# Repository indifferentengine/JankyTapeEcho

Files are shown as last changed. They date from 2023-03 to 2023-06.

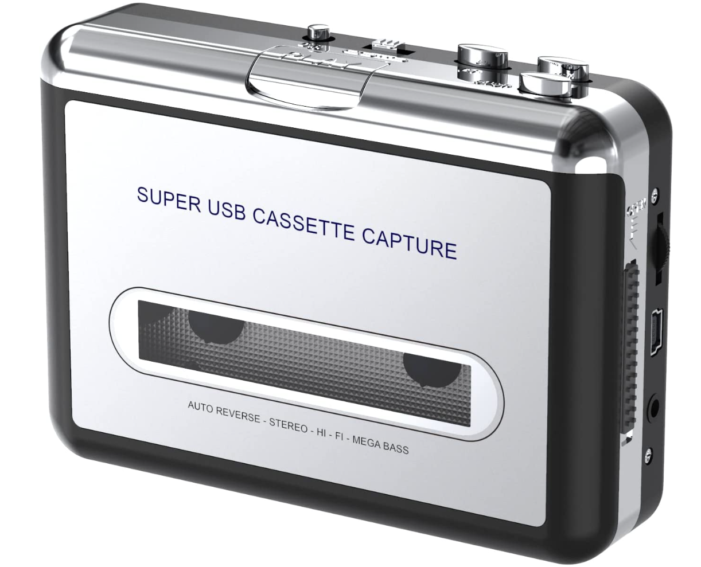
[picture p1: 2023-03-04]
Required Tape Machine.png

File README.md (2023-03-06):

# Indifferent Engine Janky Tape Echo

An open-source, DIY tape echo effect pedal built from a cheap cassette player and 3D printed parts.

# Demo Video

This is kinda what this thing sounds like.

Demonstration Video (https://www.youtube.com/watch?v=j26JLl0Hhg4)

# License

This device is licensed under GNU GPL v3. This means you are free to take this device and make any changes you like and then share those changes freely, **so long as you make the source for your changes publicly available**. This benefits everyone - because if you make some improvement, we can all benefit from it.

However, you **cannot distribute compiled versions.** In this context (a hardware device with software components), this effectively means you

a)  **cannot sell any physically manufactured device of any kind - either as parts or assembled.** 

b) **cannot charge money for access to any source, CAD files or software components that you choose to distribute** that are based upon this project.
  
If you **break these simple rules** we will force you to be front row at one of our floor shows, where we can **full-throat scream right in your sad little face.**

Everything is copyright (c) 2023 Indifferent Engine Ltd. Everything. OK?
Indifferent Engine and the Indifferent Engine glitch logo are trademarks of Indifferent Engine Ltd.

# What You Get

* STL files for 3D printed parts
* Gerber files for PCBs
* Source code for Arduino
* Bill of Materials
* CAD files in Step format.
* Eagle schematic files.
* Eagle board blanks (boards of correct dimensions with Jacks in correct locations).
* Build instructions (via our website)

# What You Don't Get

* Full Eagle board files
* Any support from us what-so-ever.

# Build guide

To show you how to put one of these together, there is a [build guide](https://www.indifferentengine.com/tapeechobuildguide) on our website.

# PCB

We sell PCBs for this project on our [merch store](https://www.indifferentengine.com/shop).

# How can we support you?

Indifferent Engine is a band, so go check out our music here:
[spotify](https://open.spotify.com/artist/0dltTUV2N49r1UjUTsqe3h?si=cdwmojcwTOmE14S_XvX_6A)

If you're having a crack at building an echo, maybe buy some parts from us on our [merch store](https://www.indifferentengine.com/shop).. All money goes back into the band for funding musical endeavours and more weird, open source pedal designs.

You can also follow us in the usual places:
[instagram](https://www.instagram.com/indifferentengine)
[facebook](https://www.facebook.com/indifferentengine)
[tiktok](https://www.tiktok.com/@indifferentengine)
[youtube](https://www.youtube.com/@indifferentengine)

And **buy a T-Shirt while you're at it**, you bunch of scallywags.

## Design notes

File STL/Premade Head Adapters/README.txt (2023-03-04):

These are pre-made head adapters to fit the Janky Tape Echo.

A word of caution:

Cassette heads are very sensitive to being aligned to the tape path correctly. 3D prints have wide tolerances
that can be hard to get right at these small scales.

Because of this, you will need to be very careful to have your 3D printer tuned up for best possible dimensional
accuracy and to use a very high quality profile (lowest possible layer height and low speed printing) to ensure the head
adapter has the tightest tolerances.

3D prints tend to shrink, some filaments more than others, and so it's impossible for us to say these head adapters will work for
everybody - they are provided as an easy "try this first" route for people. It's quite possible you'll need to design your own
head adapter to work with your setup. Check out our build guide on our website for step-by-step instructions on how to do this with free CAD software.

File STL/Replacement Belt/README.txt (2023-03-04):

This is a replacement belt for the Janky tape transport.

Print in flex filament (TPU or similar).

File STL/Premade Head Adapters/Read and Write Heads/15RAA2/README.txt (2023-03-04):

This is for 15RAA2 cassette head.

Print at highest detail possible to ensure dimensional accuracy. We print these on a Prusa Mini using the built-in Generic PLA filament profile at
0.05mm ULTRADETAIL, 15% infill in polyterra charcoal black PLA.

Space is provided around the right mounting hole (looking from the front of the head) for a spring (5mm length, 0.2mm wire, 2.5mm OD to allow pass through of M2 screw).
This allows for aziumth adjustment of the head, but is optional. If you are using the spring, place a M2 washer between the top of the spring and the underside of the head.

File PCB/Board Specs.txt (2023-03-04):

Board Specs

Mainboard:
100mm x 84mm
2 Layers
Designed to 6/6mil minimum track spacing

Control board:
126mm x 59mm
2 Layers
Designed to 6/6mil minimum track spacing

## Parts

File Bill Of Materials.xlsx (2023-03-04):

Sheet: Parts In Order Of Usage
This page contains the electronic parts in order of usage in the build instructional videos. For a complete list of parts including hardware and tools, please check the ALL PARTS page in this file. PCBs are available to buy from the bands website: https://www.indifferentengine.com Gerber files are also included in this package if you'd rather save some money and make your own boards. You cheapskate. 3D printed parts and/or kits may be available from our merch store. Take a look and see what we have. For instructions, troubleshooting tips etc. please visit the Tape Echo section of our site: https://www.indifferentengine.com/tapeecho
The Jacks
Part | Value | Description | Notes
INPUT | Audio Jack | PCB mount 3/4" audio jack
OUTPUT | Audio Jack | PCB mount 3/4" audio jack
DC1 | DC Jack | Boss-style 2.1mm DC Jack
The Ground Link
GND LINK | 0R | Zero Ohm Link | This is just a 0 Ohm link between the digital ground and analog ground. This is done to make sure there is only 1 path between digital ground and analog ground for the purposes of improving noise performance. I use a either some solid-core wire, or a discarded component leg from a resistor or capacitor to make the link.
The JST XH Headers
ERASE | 2-way JST XH Header | 2-way JST XH Male Terminal. 2.54mm lead pitch.
PLAYBACK | 2-way JST XH Header | 2-way JST XH Male Terminal. 2.54mm lead pitch.
RECORD | 2-way JST XH Header | 2-way JST XH Male Terminal. 2.54mm lead pitch.
REMOTE | 2-way JST XH Header | 2-way JST XH Male Terminal. 2.54mm lead pitch.
TAPEPWR | 2-way JST XH Header | 2-way JST XH Male Terminal. 2.54mm lead pitch.
MOTOR | 3-way JST XH Header | 3-way JST XH Male Terminal. 2.54mm lead pitch. | We use a 3 way header because we use a spare pin to ground the motor casing. This helps reduce noise.
The IDC Box Header
CNTRLBRD | IDC Box Header | 26-way IDC box header for connection to control board | Must be a 26-way, 2 row IDC box header.
12V Main Supply
D1 | 1n4001 | Polarity protection diode
C1 | 1000uF | Electrolytic capacitor, 16V, 8mm diameter
9V Bias Oscillator Supply
R26 | 10K | 1/4W Metal Film Resistor, 7.5mm diameter
R27 | 100R | 1/4W Metal Film Resistor, 7.5mm diameter
C9 | 100nF | Ceramic capacitor, 16V, 5mm diameter
C10 | 100nF | Ceramic capacitor, 16V, 5mm diameter
C11 | 10uF | Electrolytic capacitor, 16V, 5mm diameter
C12 | 1000uF | Electrolytic capacitor, 16V, 8mm diameter
9VREG | 7809 | Positive VOLTAGE REGULATOR, 9V Output | Ensure correct pinout: INPUT, GND, OUTPUT
Q5 | RFP12N10L | N-channel, logic level MOSFET | For oscillator disable control
6V Motor Supply
6VREG | 7806 | Positive VOLTAGE REGULATOR, 6V Output | Ensure correct pinout: INPUT, GND, OUTPUT
C15 | 100nF | Ceramic capacitor, 16V, 5mm diameter
C16 | 100nF | Ceramic capacitor, 16V, 5mm diameter
C17 | 10uF | Electrolytic capacitor, 16V, 5mm diameter
3V3 Tape Player Supply
3V3REG | LD1086V33 | Positive VOLTAGE REGULATOR, 3.3V Output | Ensure correct pinout: GND, OUTPUT, INPUT This is different to the other 2 regulators.
C25 | 100nF | Ceramic capacitor, 16V, 5mm diameter
C26 | 100nF | Ceramic capacitor, 16V, 5mm diameter
C27 | 10uF | Electrolytic capacitor, 16V, 5mm diameter
Buffered Virtual Ground
R10 | 10K | 1/4W Metal Film Resistor, 7.5mm diameter
R11 | 10K | 1/4W Metal Film Resistor, 7.5mm diameter
R12 | 100R | 1/4W Metal Film Resistor, 7.5mm diameter
OPAMP3 | TL072 | TL072 Dual Op Amp (or equivalent)
C20 | 100n | Ceramic capacitor, 16V, 5mm diameter
C21 | 100uF | Electrolytic capacitor, 16V, 5mm diameter
C22 | 100n | Ceramic capacitor, 16V, 5mm diameter
C23 | 100uF | Electrolytic capacitor, 16V, 5mm diameter
C24 | 100n | Ceramic capacitor, 16V, 5mm diameter
Arduino Nano
ARDUINO_NANO | Arduino Nano | Arduino Nano V3.0 Module
True Bypass Switching
R6 | 10K | 1/4W Metal Film Resistor, 7.5mm diameter
R7 | 10K | 1/4W Metal Film Resistor, 7.5mm diameter
Q4 | 2N2222 | NPN Transistor | For relay bypass switching
RELAY | 5-1462039-9 | Non-Latching, DPDT Signal Relay, 5V | https://uk.farnell.com/te-connectivity/im03pns/relay-signal-dpdt-250vac-220vdc/dp/1770596
The Motor Controller
R8 | 10K | 1/4W Metal Film Resistor, 7.5mm diameter
R9 | 100R | 1/4W Metal Film Resistor, 7.5mm diameter
D2 | 1n4001 | Back propagation protection diode
Q1 | RFP12N10L | N-channel, logic level MOSFET | High current MOSFET for motor control. Must be logic level to interface with Arduino.
C18 | 100nF | Ceramic capacitor, 16V, 5mm diameter
C19 | 1000uF | Electrolytic capacitor, 16V, 8mm diameter
Mainboard Input Stage
R4 | 4K7 | 1/4W Metal Film Resistor, 7.5mm diameter
R5 | 0R | 1/4W Metal Film Resistor, 7.5mm diameter | This is included as a way to adjust coil resistance for tuning purposes. If in doubt, use 0R (use solid core wire or a discarded component leg)
R13 | 1K | 1/4W Metal Film Resistor, 7.5mm diameter
R14 | 1M | 1/4W Metal Film Resistor, 7.5mm diameter
R15 | 1K | 1/4W Metal Film Resistor, 7.5mm diameter
R16 | 1K | 1/4W Metal Film Resistor, 7.5mm diameter
R17 | 400R | 1/4W Metal Film Resistor, 7.5mm diameter
R18 | 100K | 1/4W Metal Film Resistor, 7.5mm diameter
OPAMP2 | TL072 | TL072 Dual Op Amp (or equivalent)
C13 | *pF | Film capacitor, 100V, 5mm diameter | For tuning bias trap notch filter. A good starting place is C13 as 1nF and C14 as NONE. Must be 100V rated
C14 | *pF | Film capacitor, 100V, 5mm diameter | Optional. Extra capacitor space for combining values with C13 (to make non-standard cap values for trap tuning) Must be 100V rated
C28 | 100n | Film capacitor, 16V, 5mm diameter
C29 | 100n | Ceramic capacitor, 16V, 5mm diameter
C30 | 100pF | Film capacitor, 16V, 5mm diameter
C31 | 10uF | Electrolytic capacitor, 100V, 5mm diameter | Must be 100V rated
INDUCTOR | 10mH | Radial Inductor | For bias trap. If different value used, capacitors C13 and C14 in the tank circuit must be calculated accordingly.
Mainboard Output Stage
R19 | 1M | 1/4W Metal Film Resistor, 7.5mm diameter
R20 | 22K | 1/4W Metal Film Resistor, 7.5mm diameter
R21 | 22K | 1/4W Metal Film Resistor, 7.5mm diameter
R22 | 10K | 1/4W Metal Film Resistor, 7.5mm diameter
R23 | 1K | 1/4W Metal Film Resistor, 7.5mm diameter
R24 | 1M | 1/4W Metal Film Resistor, 7.5mm diameter
R25 | 560R | 1/4W Metal Film Resistor, 7.5mm diameter
OPAMP1 | TL072 | TL072 Dual Op Amp (or equivalent)
C32 | 220n | Film capacitor, 16V, 5mm diameter
C33 | 1nF | Film capacitor, 16V, 5mm diameter
C34 | 2.2nF | Film capacitor, 16V, 5mm diameter
C35 | 100pF | Film capacitor, 16V, 5mm diameter
C36 | 100n | Ceramic capacitor, 16V, 5mm diameter
C37 | 10uF | Electrolytic capacitor, 16V, 5mm diameter
Control Board IDC Header
MAINBOARD | IDC Box Header | 26-way IDC box header for connection to control board | Must be a 26-way, 2 row IDC box header.
Control Board JST XH Headers
HEAD_LONG | 3-way JST XH Header | 3-way JST XH Male Terminal. 2.54mm lead pitch.
HEAD_OUT | 3-way JST XH Header | 3-way JST XH Male Terminal. 2.54mm lead pitch.
HEAD_SHORT | 3-way JST XH Header | 3-way JST XH Male Terminal. 2.54mm lead pitch.
Control Board Bias Trap
INDUCTOR | 10mH | Radial Inductor | For bias trap. If different value used, capacitors C6 and C7 in the tank circuit must be calculated accordingly.
C6 | *pF | Film capacitor, 16V, 5mm diameter | For tuning bias trap notch filter. A good starting place is C13 as 1nF and C14 as NONE.
C7 | *pF | Film capacitor, 16V, 5mm diameter | Optional. Extra capacitor space for combining values with C13 (to make non-standard cap values for trap tuning)
Control Board Input Filtering and Feedback Mix
R4 | 1K6 | 1/4W Metal Film Resistor, 7.5mm diameter
R7 | 2K2 | 1/4W Metal Film Resistor, 7.5mm diameter
R8 | 2K2 | 1/4W Metal Film Resistor, 7.5mm diameter
R9 | 2K2 | 1/4W Metal Film Resistor, 7.5mm diameter
R10 | 1K | 1/4W Metal Film Resistor, 7.5mm diameter
R11 | 1K | 1/4W Metal Film Resistor, 7.5mm diameter
R12 | 100K | 1/4W Metal Film Resistor, 7.5mm diameter
R13 | 2K2 | 1/4W Metal Film Resistor, 7.5mm diameter
R14 | 10K | 1/4W Metal Film Resistor, 7.5mm diameter
R15 | 10K | 1/4W Metal Film Resistor, 7.5mm diameter
R16 | 100K | 1/4W Metal Film Resistor, 7.5mm diameter
R17 | 1M | 1/4W Metal Film Resistor, 7.5mm diameter
OPAMP1 | TL072 | TL072 Op Amp (or equivalent)
OPAMP2 | TL072 | TL072 Op Amp (or equivalent)
BASS | 10K | Trimpot
TREBLE | 10K | Trimpot
C2 | 100nF | Ceramic capacitor, 16V, 5mm diameter
C3 | 18nF | Film capacitor, 16V, 5mm diameter
C4 | 220nF | Film capacitor, 16V, 5mm diameter
C5 | 100nF | Ceramic capacitor, 16V, 5mm diameter
Control Board Output Stage
R5 | 1K | 1/4W Metal Film Resistor, 7.5mm diameter
R6 | 1M | 1/4W Metal Film Resistor, 7.5mm diameter
POSTGAIN | 10K | Trimpot
C1 | 10nF | Film capacitor, 16V, 5mm diameter
Front Panel Potentiometers
TIME | 10K Linear | 9mm Alpha Potentiometer, Metal D-Shaft
BRIGHTNES | 50K Linear | 9mm Alpha Potentiometer, Metal D-Shaft
FEEDBACK | 10K Linear | 9mm Alpha Potentiometer, Metal D-Shaft
GAIN | 10K Linear | 9mm Alpha Potentiometer, Metal D-Shaft
MIX | 100K Linear | 9mm Alpha Potentiometer, Metal D-Shaft
JANK | 10K Linear | 9mm Alpha Potentiometer, Metal D-Shaft
Head Select Switch
HEAD SWITCH | 3PDT Toggle | Panel mounted 3PDT On-On toggle switch
Bias Oscillator
R1 | 10K | 1/4W Metal Film Resistor, 7.5mm diameter
R2 | 10K | 1/4W Metal Film Resistor, 7.5mm diameter
R3 | 1K | 1/4W Metal Film Resistor, 7.5mm diameter
Q2 | BC327 | PNP Transistor
Q3 | BC337 | NPN Transistror
C2 | 22uF | Electrolytic capacitor, 100V, 5mm diameter | Must be 100V rated.
C3 | 22uF | Electrolytic capacitor, 100V, 5mm diameter | Must be 100V rated
C4 | 1uF | Ceramic multilayer capacitor, 100V | Must be 100V rated
C5 | 10nF | Film capacitor, 100V, 5mm diameter | Must be 100V rated
C6 | 100nF | Ceramic multilayer capacitor, 100V | Must be 100V rated
C7 | 100nF | Ceramic multilayer capacitor, 100V | Must be 100V rated
C8 | 100pF | Film capacitor, 100V, 5mm diameter | Must be 100V rated
BIASLEVEL | 100K | Trimpot | Bias attenuator

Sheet: ALL PARTS
MAIN BOARD
Part | Value | Description | Notes | Useful Links
3V3REG | LD1086V33 | Positive VOLTAGE REGULATOR, 3.3V Output | Ensuire correct pinout: GND, OUTPUT, INPUT This is different to the other 2 regulators.
6VREG | 7806 | Positive VOLTAGE REGULATOR, 6V Output | Ensuire correct pinout: INPUT, GND, OUTPUT
9VREG | 7809 | Positive VOLTAGE REGULATOR, 9V Output | Ensuire correct pinout: INPUT, GND, OUTPUT
ARDUINO_NANO | Arduino Nano | Arduino Nano V3.0 Module
OPAMP1 | TL072 | TL072 Dual Op Amp (or equivalent)
OPAMP2 | TL072 | TL072 Dual Op Amp (or equivalent)
OPAMP3 | TL072 | TL072 Dual Op Amp (or equivalent)
D1 | 1n4001 | Polarity protection diode
D2 | 1n4001 | Back propagation protection diode
Q1 | RFP12N10L | N-channel, logic level MOSFET | High current MOSFET for motor control. Must be logic level to interface with Arduino.
Q2 | BC327 | PNP Transistror
Q3 | BC337 | NPN Transistor
Q4 | 2N2222 | NPN Transistor | For relay bypass switching
Q5 | RFP12N10L | N-channel, logic level MOSFET | For oscillator disable control
INDUCTOR | 10mH | Radial Inductor | For bias trap. If different value used, capacitors C13 and C14 in the tank circuit must be calculated accordingly.
C1 | 1000uF | Electrolytic capacitor, 16V, 8mm diameter
C2 | 22uF | Electrolytic capacitor, 100V, 5mm diameter | Must be 100V rated
C3 | 22uF | Electrolytic capacitor, 100V, 5mm diameter | Must be 100V rated
C4 | 1uF | Ceramic multilayer capacitor, 100V | Must be 100V rated
C5 | 10nF | Film capacitor, 100V, 5mm diameter | Must be 100V rated
C6 | 100nF | Ceramic multilayer capacitor, 100V | Must be 100V rated
C7 | 100nF | Ceramic multilayer capacitor, 100V | Must be 100V rated
C8 | 100pF | Film capacitor, 100V, 5mm diameter | Must be 100V rated
C9 | 100nF | Ceramic capacitor, 16V, 5mm diameter
C10 | 100nF | Ceramic capacitor, 16V, 5mm diameter
C11 | 10uF | Electrolytic capacitor, 16V, 5mm diameter
C12 | 1000uF | Electrolytic capacitor, 16V, 8mm diameter
C13 | *pF | Film capacitor, 100V, 5mm diameter | For tuning bias trap notch filter. A good starting place is C13 as 1nF and C14 as NONE. Must be 100V rated
C14 | *pF | Film capacitor, 100V, 5mm diameter | Optional. Extra capacitor space for combining values with C13 (to make non-standard cap values for trap tuning) Must be 100V rated
C15 | 100nF | Ceramic capacitor, 16V, 5mm diameter
C16 | 100nF | Ceramic capacitor, 16V, 5mm diameter
C17 | 10uF | Electrolytic capacitor, 16V, 5mm diameter
C18 | 100nF | Ceramic capacitor, 16V, 5mm diameter
C19 | 1000uF | Electrolytic capacitor, 16V, 8mm diameter
C20 | 100n | Ceramic capacitor, 16V, 5mm diameter
C21 | 100uF | Electrolytic capacitor, 16V, 5mm diameter
C22 | 100n | Ceramic capacitor, 16V, 5mm diameter
C23 | 100uF | Electrolytic capacitor, 16V, 5mm diameter
C24 | 100n | Ceramic capacitor, 16V, 5mm diameter
C25 | 100nF | Ceramic capacitor, 16V, 5mm diameter
C26 | 100nF | Ceramic capacitor, 16V, 5mm diameter
C27 | 10uF | Electrolytic capacitor, 16V, 5mm diameter
C28 | 100n | Film capacitor, 16V, 5mm diameter
C29 | 100n | Ceramic capacitor, 16V, 5mm diameter
C30 | 100pF | Film capacitor, 16V, 5mm diameter
C31 | 10uF | Electrolytic capacitor, 100V, 5mm diameter | Must be 100V rated
C32 | 220n | Film capacitor, 16V, 5mm diameter
C33 | 1nF | Film capacitor, 16V, 5mm diameter
C34 | 2.2nF | Film capacitor, 16V, 5mm diameter
C35 | 100pF | Film capacitor, 16V, 5mm diameter
C36 | 100n | Ceramic capacitor, 16V, 5mm diameter
C37 | 10uF | Electrolytic capacitor, 16V, 5mm diameter
BIASLEVEL | 100K | Trimpot | Bias attenuator trimpot.
R1 | 10K | 1/4W Metal Film Resistor, 7.5mm diameter
R2 | 10K | 1/4W Metal Film Resistor, 7.5mm diameter
R3 | 1K | 1/4W Metal Film Resistor, 7.5mm diameter
R4 | 4K7 | 1/4W Metal Film Resistor, 7.5mm diameter
R5 | 0R | 1/4W Metal Film Resistor, 7.5mm diameter | This is included as a way to adjust coil resistance for tuning purposes. If in doubt, use 0R (use solid core wire or a discarded component leg)
R6 | 10K | 1/4W Metal Film Resistor, 7.5mm diameter
R7 | 10K | 1/4W Metal Film Resistor, 7.5mm diameter
R8 | 10K | 1/4W Metal Film Resistor, 7.5mm diameter
R9 | 100R | 1/4W Metal Film Resistor, 7.5mm diameter
R10 | 10K | 1/4W Metal Film Resistor, 7.5mm diameter
R11 | 10K | 1/4W Metal Film Resistor, 7.5mm diameter
R12 | 100R | 1/4W Metal Film Resistor, 7.5mm diameter
R13 | 1K | 1/4W Metal Film Resistor, 7.5mm diameter
R14 | 1M | 1/4W Metal Film Resistor, 7.5mm diameter
R15 | 1K | 1/4W Metal Film Resistor, 7.5mm diameter
R16 | 1K | 1/4W Metal Film Resistor, 7.5mm diameter
R17 | 400R | 1/4W Metal Film Resistor, 7.5mm diameter
R18 | 100K | 1/4W Metal Film Resistor, 7.5mm diameter
R19 | 1M | 1/4W Metal Film Resistor, 7.5mm diameter
R20 | 22K | 1/4W Metal Film Resistor, 7.5mm diameter
R21 | 22K | 1/4W Metal Film Resistor, 7.5mm diameter
R22 | 10K | 1/4W Metal Film Resistor, 7.5mm diameter
R23 | 1K | 1/4W Metal Film Resistor, 7.5mm diameter
R24 | 1M | 1/4W Metal Film Resistor, 7.5mm diameter
R25 | 560R | 1/4W Metal Film Resistor, 7.5mm diameter
R26 | 10K | 1/4W Metal Film Resistor, 7.5mm diameter
R27 | 100R | 1/4W Metal Film Resistor, 7.5mm diameter
RELAY | 5-1462039-9 | Non-Latching, DPDT Signal Relay, 5V | https://uk.farnell.com/te-connectivity/im03pns/relay-signal-dpdt-250vac-220vdc/dp/1770596
CNTRLBRD | IDC Box Header | 26-way IDC box header for connection to control board | I found these on E-bay. Must be a 26-way IDC box header.
DC1 | DC Jack | Boss-style 2.1mm DC Jack
INPUT | Audio Jack | PCB mount 3/4" audio jack
OUTPUT | Audio Jack | PCB mount 3/4" audio jack
ERASE | 2-way JST XH Header | 2-way JST XH Male Terminal. 2.54mm lead pitch.
PLAYBACK | 2-way JST XH Header | 2-way JST XH Male Terminal. 2.54mm lead pitch.
RECORD | 2-way JST XH Header | 2-way JST XH Male Terminal. 2.54mm lead pitch.
REMOTE | 2-way JST XH Header | 2-way JST XH Male Terminal. 2.54mm lead pitch.
TAPEPWR | 2-way JST XH Header | 2-way JST XH Male Terminal. 2.54mm lead pitch.
HEAD_LONG | 3-way JST XH Header | 3-way JST XH Male Terminal. 2.54mm lead pitch.
HEAD_OUT | 3-way JST XH Header | 3-way JST XH Male Terminal. 2.54mm lead pitch.
HEAD_SHORT | 3-way JST XH Header | 3-way JST XH Male Terminal. 2.54mm lead pitch.
MOTOR | 3-way JST XH Header | 3-way JST XH Male Terminal. 2.54mm lead pitch. | We use a 3 way header because we use a spare pin to ground the motor casing. This helps reduce noise.
GND LINK | 0R | Zero Ohm Link | This is just a 0 Ohm link between the digital ground and analog ground. This is done to make sure there is only 1 path between digital ground and analog ground for the purposes of improving noise performance. I use a either some solid-core wire, or a discarded component leg from a resistor or capacitor to make the link.
CONTROL BOARD
Part | Value | Description | Notes
OPAMP1 | TL072 | TL072 Op Amp (or equivalent)
OPAMP2 | TL072 | TL072 Op Amp (or equivalent)
Q1 | RFP12N10L | N-channel, logic level MOSFET | Optional, for LED strip lighting. Must be logic level to interface with Arduino.
INDUCTOR | 10mH | Radial Inductor | For bias trap. If different value used, capacitors C13 and C14 in the tank circuit must be calculated accordingly.
C1 | 10nF | Film capacitor, 16V, 5mm diameter
C2 | 100nF | Ceramic capacitor, 16V, 5mm diameter
C3 | 18nF | Film capacitor, 16V, 5mm diameter
C4 | 220nF | Film capacitor, 16V, 5mm diameter
C5 | 100nF | Ceramic capacitor, 16V, 5mm diameter
C6 | *pF | Film capacitor, 100V, 5mm diameter | For tuning bias trap notch filter. A good starting place is C13 as 1nF and C14 as NONE. Must be 100V rated
C7 | *pF | Film capacitor, 100V, 5mm diameter | Optional. Extra capacitor space for combining values with C13 (to make non-standard cap values for trap tuning) Must be 100V rated
R4 | 1K6 | 1/4W Metal Film Resistor, 7.5mm diameter
R5 | 1K | 1/4W Metal Film Resistor, 7.5mm diameter | Sets minimum position of brightness control.
R6 | 1M | 1/4W Metal Film Resistor, 7.5mm diameter
R7 | 2K2 | 1/4W Metal Film Resistor, 7.5mm diameter
R8 | 2K2 | 1/4W Metal Film Resistor, 7.5mm diameter
R9 | 2K2 | 1/4W Metal Film Resistor, 7.5mm diameter
R10 | 1K | 1/4W Metal Film Resistor, 7.5mm diameter
R11 | 1K | 1/4W Metal Film Resistor, 7.5mm diameter
R12 | 100K | 1/4W Metal Film Resistor, 7.5mm diameter
R13 | 2K2 | 1/4W Metal Film Resistor, 7.5mm diameter
R14 | 10K | 1/4W Metal Film Resistor, 7.5mm diameter
R15 | 10K | 1/4W Metal Film Resistor, 7.5mm diameter
R16 | 100K | 1/4W Metal Film Resistor, 7.5mm diameter
R17 | 1M | 1/4W Metal Film Resistor, 7.5mm diameter
TIME | 10K Linear | 9mm Alpha Potentiometer, Metal D-Shaft |  | https://www.thonk.co.uk/shop/alpha-9mm-pots-dshaft/
BRIGHTNES | 50K Linear | 9mm Alpha Potentiometer, Metal D-Shaft |  | https://www.thonk.co.uk/shop/alpha-9mm-pots-dshaft/
FEEDBACK | 10K Linear | 9mm Alpha Potentiometer, Metal D-Shaft |  | https://www.thonk.co.uk/shop/alpha-9mm-pots-dshaft/
GAIN | 10K Linear | 9mm Alpha Potentiometer, Metal D-Shaft |  | https://www.thonk.co.uk/shop/alpha-9mm-pots-dshaft/
MIX | 100K Linear | 9mm Alpha Potentiometer, Metal D-Shaft |  | https://www.thonk.co.uk/shop/alpha-9mm-pots-dshaft/
JANK | 10K Linear | 9mm Alpha Potentiometer, Metal D-Shaft |  | https://www.thonk.co.uk/shop/alpha-9mm-pots-dshaft/
BASS | 10K | Trimpot
TREBLE | 10K | Trimpot
POSTGAIN | 10K | Trimpot
MAINBRD | IDC Box Header | 26-way IDC box header for connection to control board | I found these on E-bay. Must be a 26-way IDC box header.
LED+ | LED Strip | 12V LED Strip, Positive terminal | Optional, for LED strip lighting
LED- | LED Strip | 12V LED Strip, Negative terminal | Optional, for LED strip lighting
Hardware
2mm diameter steel rod | 5 x 12mm lengths |  | To fit 12mm length - leaves ~1 mm space for easy fit. Can be cut to length with some strong pliers. Also available online from suppliers who will cut it to length for you. | https://www.rapidmetals.co.uk/product/stainless-316-round-2mm/
3 x M2 8mm Hex bolts |  |  | For mounting the cassette transport to the transport mount
M2 washers (various number, see notes) |  |  | For mounting cassette player to transport mount. These take up the extra distance between the 3D printed part and the transport - how many is needed varies between 6 and 10.
12 x M2 Hex Bolts (various length, see notes) |  |  | For mounting heads and head adapters. Length of bolts required depends on the size of your heads and adapters.
1 x M3 4mm Hex bolt |  |  | 1 x 4mm for attaching terminal washer to enclosure body (optional, for shielding)
11 x M3 8mm Hex bolts |  |  | 4 x 8mm for guide toppers 3 x 8mm for connecting transport mount to head mount 4 x 8mm for attaching acrylic window
4 x M3 16mm Hex bolts |  |  | For attaching reel clamps
4 x M4 65mm Hex Bolts |  |  | For the enclosure - bolts together the bottom plate, main body and enclosure lid.
15 x M3 Heat-Set Inserts |  |  | Brass, threaded inserts to be installed into the 3D printed parts using a soldering iron (and optional heat-set insert bit). The inserts allow us to open and close the enclosure many times for servicing without worrying about stripping the 3D printed plastic with the bolts.
4 x M4 Heat-Set Inserts |  |  | Brass, threaded inserts to be installed into the 3D printed parts using a soldering iron (and optional heat-set insert bit). The inserts allow us to open and close the enclosure many times for servicing without worrying about stripping the 3D printed plastic with the bolts.
6 x M3 Grub screw |  |  | 6 x 8mm M3 grub screws for attaching 3D printed knobs | https://www.aliexpress.com/item/33029779249.html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
Acrylic window |  |  | Clear acrylic - you can order this cut to size and drilled from many suppliers. I use SimplyPlastics. Specs are: Thickness: 5mm Length: 130mm Width: 65mm Corner Radius: 5mm Polished: Yes, Holes: 4 holes, one for each corner Hole diameter: 3mm at 10mm in from the edge. Holes countersunk: No If you know how then you can almost certainly do this much cheaper
3D Printer filament |  |  | PLA or PETG filaments are both suitable. I estimate ~440g of filament based on my slicer settings. At £25 for a 1KG roll, that's around £11 of filament
TO-220 Clip-On Heatsink |  |  | Heatsink for the 5V regulator. Clip-on heatsinks are available for TO-220 packages. This regulator generates a great deal of heat, and so I strongly recommend heatsinking your 5V regulator to extend its life.
1 x M3 wire ring terminal |  |  | A ring terminal washer for connecting a grounding wire to the enclosure body (if shielding is used)
Stereo angled 3.5mm audio cable |  |  | For connecting tape machine headphone jack to mainboard. Must be kind with 3 conductors (left, right, ground). We will cut one of the jacks off and cut the wire down to 10cm length. This must be angled, lest it not fit into the machine. See the link for an example. | https://smile.amazon.co.uk/gp/product/B072TYZ89H/ref=ppx_yo_dt_b_asin_title_o05_s00?ie=UTF8&psc=1
Bearings | 10 x (2mmx5mmx2mm) |  | Optional but recommended.Ten 682ZZ 2x5x2 bearings for tape path. These are placed over the steel tape guides to form a simple roller. This improves the smoothness of the tape path to lower flutter at low tape speeds. If you want a particularly lo-fi sounding device then leave these out! | https://www.aliexpress.com/item/33007670757.html
Tools
3D Printer |  |  | Hobbyist FDM 3D Printer with a useable print volume of 160mm x 150mm x 50mm or bigger.
Soldering Iron |  |  | Ideally with adjustable temperature for use with heat-set inserts.
Oscilloscope |  |  | A cheap hobbyist scope will do. These can be had quite cheap from places like Amazon (around £30)
Desoldering pump |  |  | Optional but recommended - for removing connectors from cassette machine PCB
Strong pliers |  |  | For cutting steel rods
Allen keys for M2, M3 and M4 bolts |  |  | For general assembly
Small phillps head screwdriver |  |  | For disassembling cassette machine
Small flat head screwdriver |  |  | For disassembling cassette machine
Anti-static tweezers |  |  | For installing the tape loop into the machine. Only the criminally insane would try to make loops without these.
A PC or Mac with USB connection |  |  | For flashing software to the Arduino for motor and switch control
Wire strippers
Calipers |  |  | Optional but recommended - preferably digital ones - these can be had online for quite cheap.
Set of Spanners |  |  | For tightening down the nuts on the potentiometers and jacks. Sizes depend on the parts used, but usually between 10mm and 14mm
Heat-set insert tool |  |  | A bit for your soldering iron that makes it easier to install heat-set inserts. Optional but recommended
Hot glue gun with glue |  |  | Optional but recommended. For securing wiring headers and ribbon cable in final assembly. Makes the machine a little more robust for use on the road by preventing wires from coming loose from the headers, whilst still allowing the machine to be easily serviced.
Lighter or heat gun |  |  | For using heat shrink tubing
Other
12V Power Supply |  |  | Negative tip, 2.1mm boss-style barrel plug 12V supply. Recommend 1A.
3PDT On-On toggle switch |  |  | For head select switch
2 Cassettes |  |  | Ideally at least one should be reel-to-reel so that you can steal the reels. Also ensure 1 has good quality tape for making tape loops with. Reel to reel cassettes can be a bit on the pricey side, so you can of course use standard audio cassettes, especially when you first start out if you need to keep costs down. It will just mean you need to change out your loops much more often. Audio cassettes are very cheap in comparison - you can use the tape from any cassette - our bass player, Alex, turned up to practice one day with a carrier bag full to the brim with old cassettes he picked up at a boot sale for the princely sum of £1. However, if you do spend a bit extra for some quality tapes it can make a big difference; I find a loop made from typical audio cassette lasts only around 3 hours of constant operation, where-as computer cassette lasts on the order of days of constant operation. You can also print cassette reels if you want to save some money, or just fancy a customised look; here's one available on thingiverse: https://www.thingiverse.com/thing:2735583
Sticky tape |  |  | Scotch tape or cellotape. For splicing your tape loops. If you want to do it more pro, find some 1/8" cassette splicing tape. If you want to be super pro, grab yourself a 1/8" splicing block, too. The cleaner and better your splice, the more reliable the loop will be and the longer it will last in the machine. A badly spliced loop is the most common cause of a jam or tape failure.
Stranded AWG22 hook up wire |  |  | A bunch of this in different colours is useful. I use 1/0.6mm wire
Shielded 2 core audio wire |  |  | A bunch of shielded, 2 core wire audio wire for connecting heads and tape machine to mainboard
Heat shrink tubing |  |  | For securing spliced wires and protecting from shorts
Cassette player |  |  | Must be "reshow" or equivalent. There are many portable cassette players on Amazon and similar that are all the same tape machine that has been re-badged. I've seen them listed as: Reshow DIGITNOW! Rybozen BW Cassette. PH4SBD Cassette Player They usually say "Super USB Cassette Capture" on the side and have a USB connection function. Example: https://www.aliexpress.com/item/1005001695869889.html?curPageLogUid=aDCpCwiYYIHt They look like the image to the right. The colours vary. You can usually tell it's built from the same transport by looking at the configuration of buttons along the top - they're always the same.
Cassette Active Erase Head |  |  | Must be an active erase head, not a passive magnet. | https://www.aliexpress.com/item/1005002218775351.html?curPageLogUid=ime3KjTHvnrh
2 x Cassette read/write head |  |  | 2 standard cassette read/write heads. Read and write heads for cassettes are interchangeable. Can be mono or stereo. | https://www.aliexpress.com/item/1005002682699258.html?curPageLogUid=lfhhyxj9CqwW
2 x Spring |  |  | Optional For azimuth adjustment of read/write heads. Inner diameter should be 2mm to accept M2 bolt. Outter diameter 3mm. | https://www.aliexpress.com/item/4001071467098.html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
Mono open chassis-mount 1/4" jack |  |  | For the remote bypass switch connection
Indifferent Engine PCBs |  |  | For Mainboard and Controlboard. You can make/source these yourself using the included gerber files, or if you want to support us you can buy these from our merch store at https://www.indifferentengine.com/shop
Mini USB cable |  |  | For connecting the Arduino Nano to a PC or Mac so that you can copy the software to it. Make sure it's a DATA cable, not just a charging cable.
Conductive paint |  |  | Optional. For applying EM shielding to the machine enclosure.
Thermal compound |  |  | For 5V regulator heatsink. Helps conduct heat into the heatsink and away from the regulator.
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

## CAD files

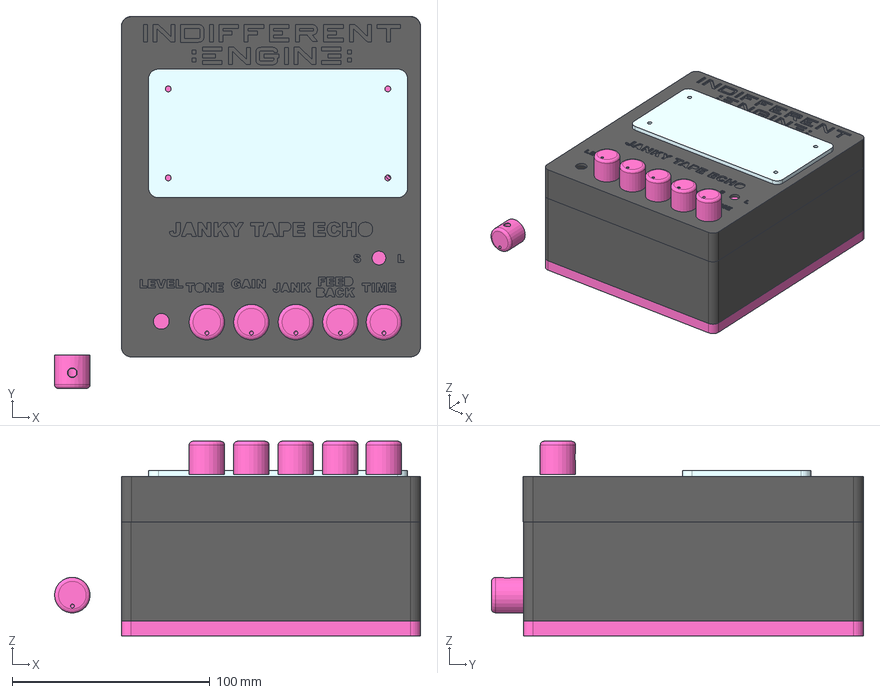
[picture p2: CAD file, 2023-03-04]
CAD/Step/Janky Tape Echo MkII.step
185.0 x 188.1 x 98.4 mm
EnclosureBottomPlate
GuideTopper2
EnclosureBody
EnclosureLid
GuideTopper1
GlassDummy
HeadMount (1)
TransportMount
ReelTopClamp1
ReelTopClamp2
Knob_DShaft x 6

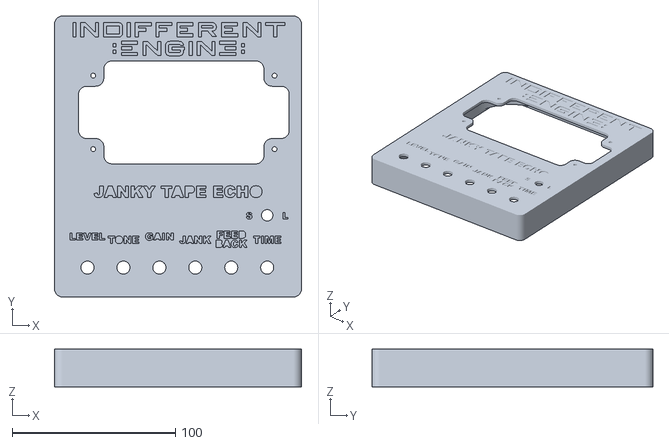
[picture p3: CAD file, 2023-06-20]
STL/EnclosureLid.stl
151.2 x 172.0 x 23.0

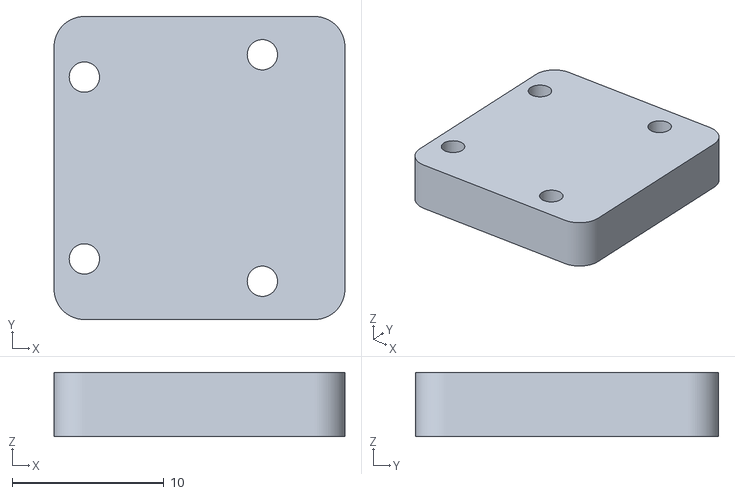
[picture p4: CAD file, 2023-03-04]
STL/Premade Head Adapters/Erase Heads/LE17B/HeadAdatper_LE17B.stl
19.2 x 20.0 x 4.25

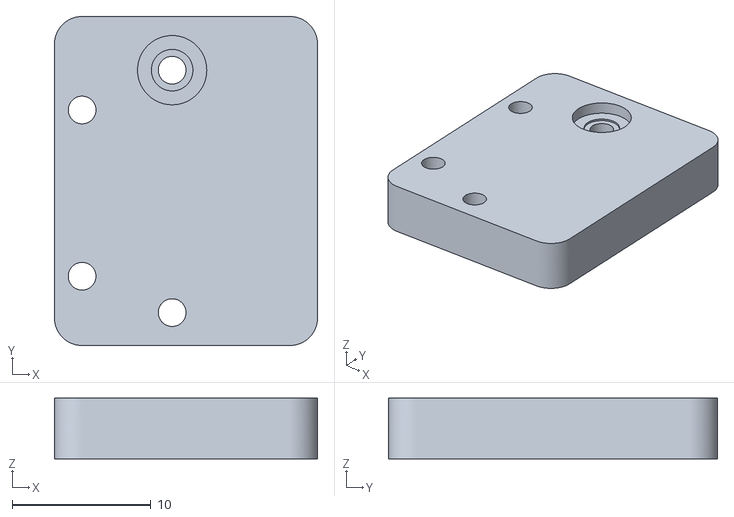
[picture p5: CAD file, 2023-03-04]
STL/Premade Head Adapters/Read and Write Heads/15RAA2/15RAA2.stl
19.0 x 23.8 x 4.40

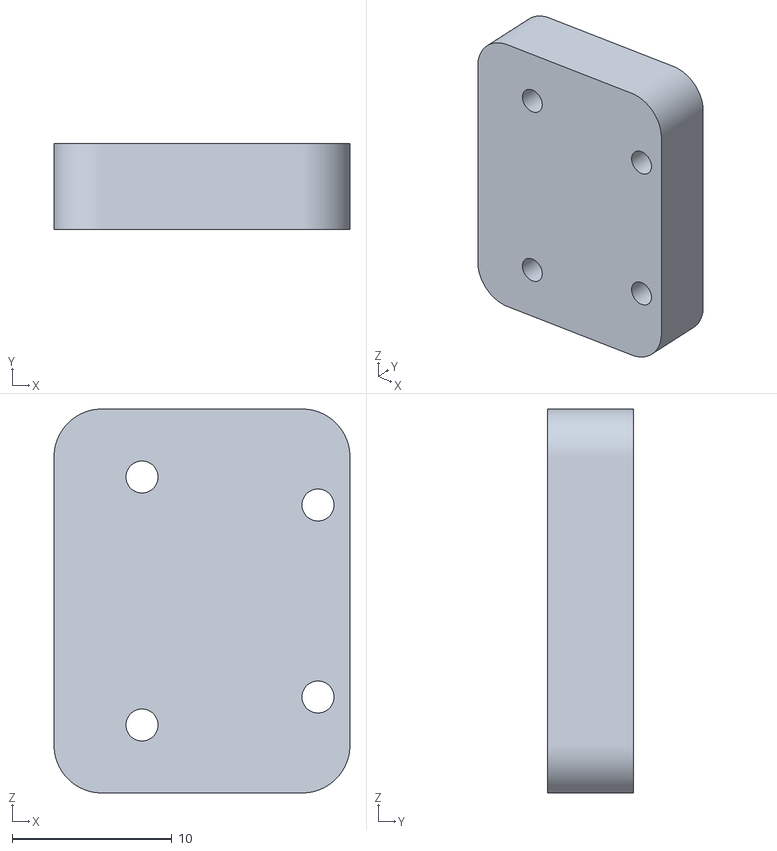
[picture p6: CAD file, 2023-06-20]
STL/Premade Head Adapters/Read and Write Heads/25PBK8/25PBK8.stl
18.5 x 5.40 x 24.0

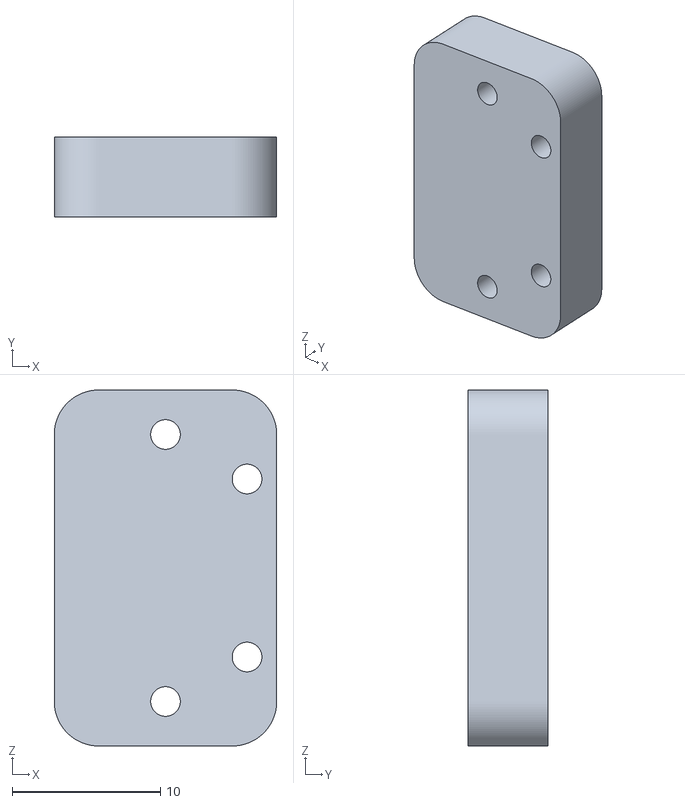
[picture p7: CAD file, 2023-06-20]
STL/Premade Head Adapters/Read and Write Heads/TC62/TC62.stl
15.0 x 5.40 x 24.0

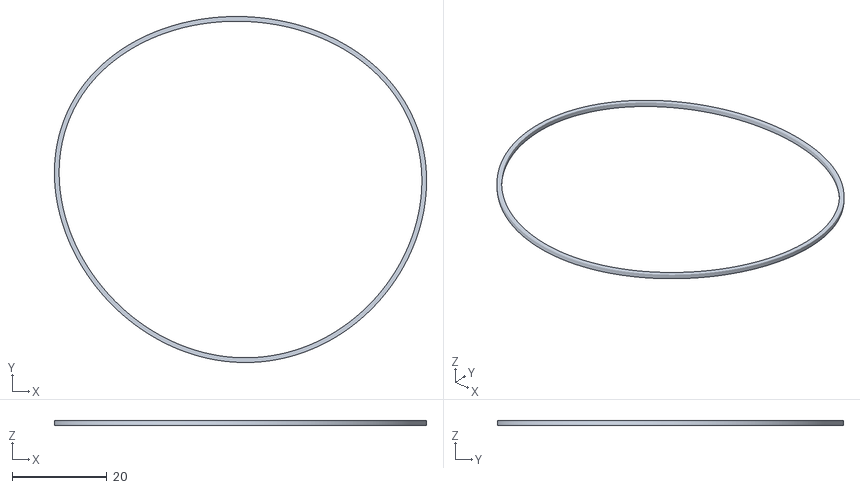
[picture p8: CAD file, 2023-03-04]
STL/Replacement Belt/Belt.stl
78.5 x 72.9 x 1.00

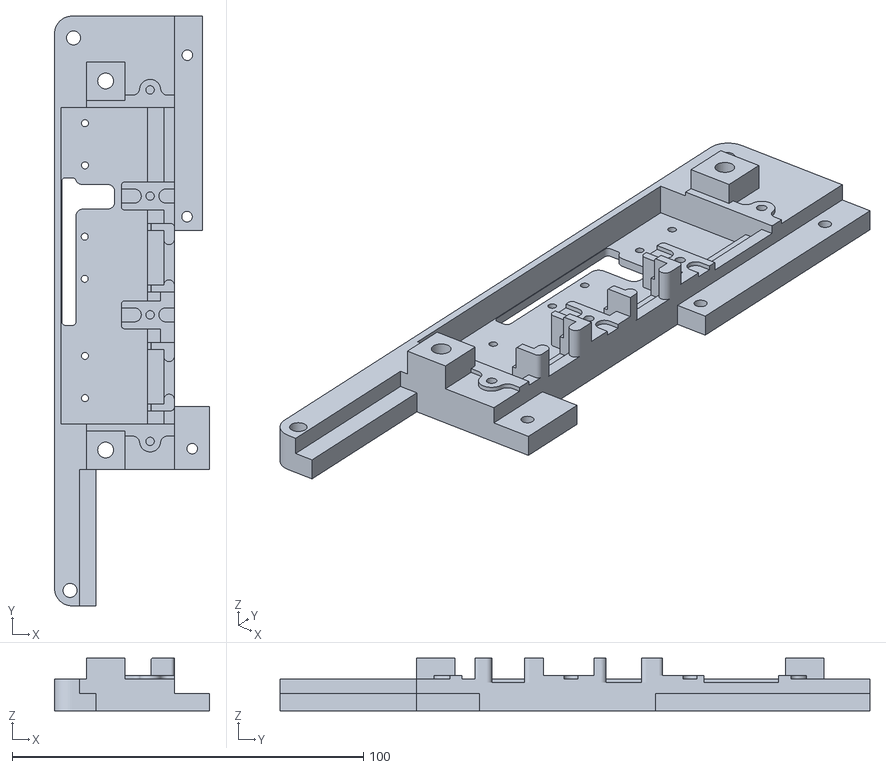
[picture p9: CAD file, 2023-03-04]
STL/Head Mount.stl
44.1 x 167.8 x 15.0

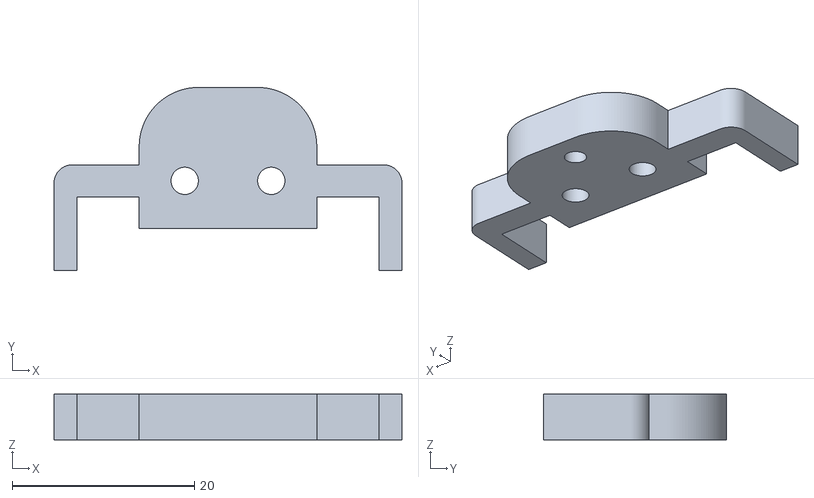
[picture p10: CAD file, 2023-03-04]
STL/Guide Topper 1.stl
38.2 x 20.1 x 5.00

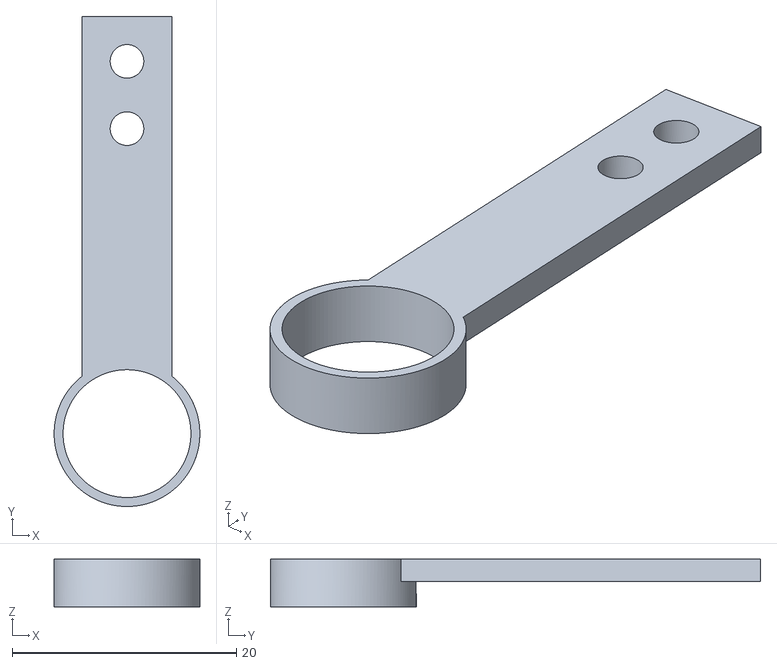
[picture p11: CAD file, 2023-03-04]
STL/Reel Clamp.stl
13.0 x 43.7 x 4.25

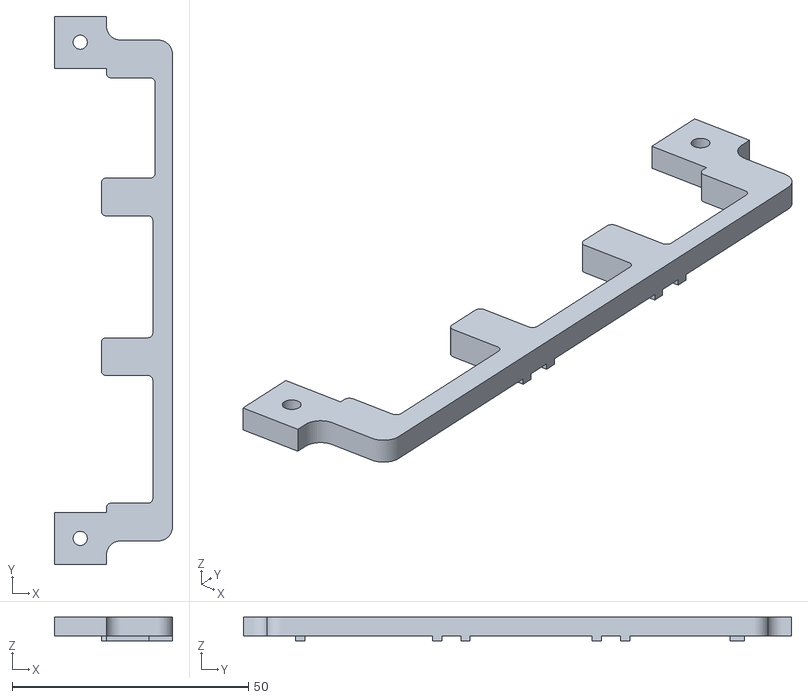
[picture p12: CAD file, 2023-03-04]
STL/Guide Topper 2.stl
25.0 x 116.0 x 5.01

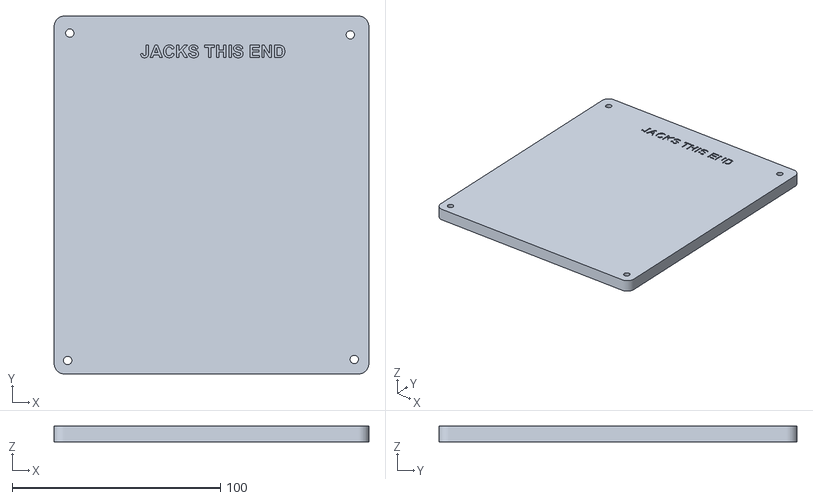
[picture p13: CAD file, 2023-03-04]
STL/Enclosure Bottom Plate.stl
151.2 x 172.0 x 7.50

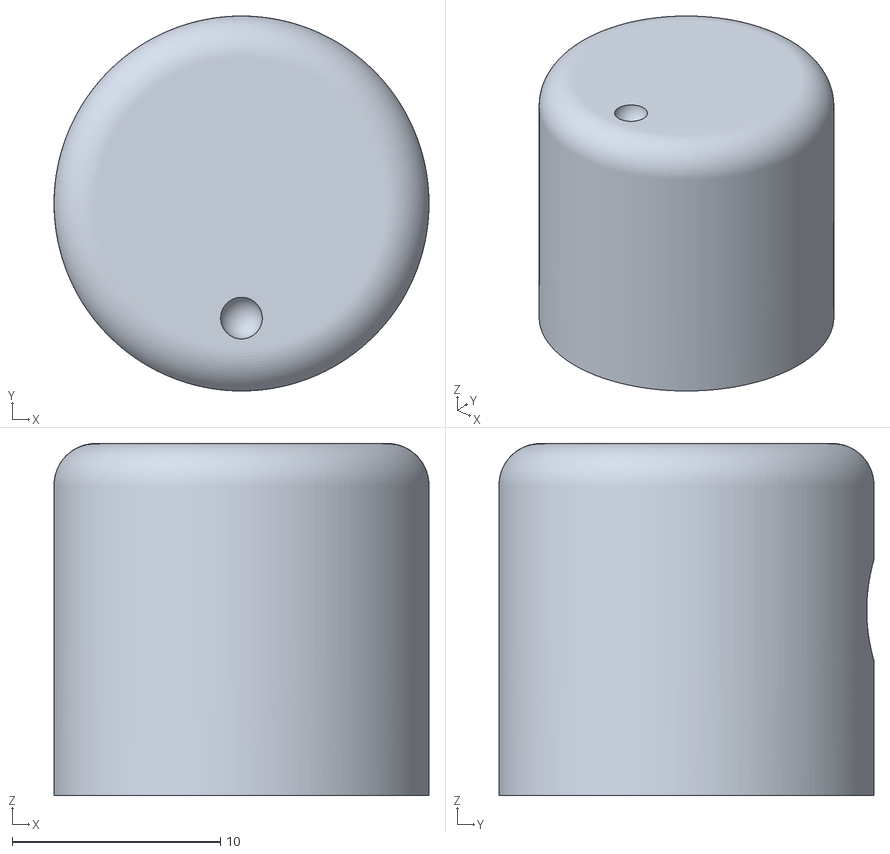
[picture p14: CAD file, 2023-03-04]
STL/Knob.stl
18.0 x 18.0 x 16.9

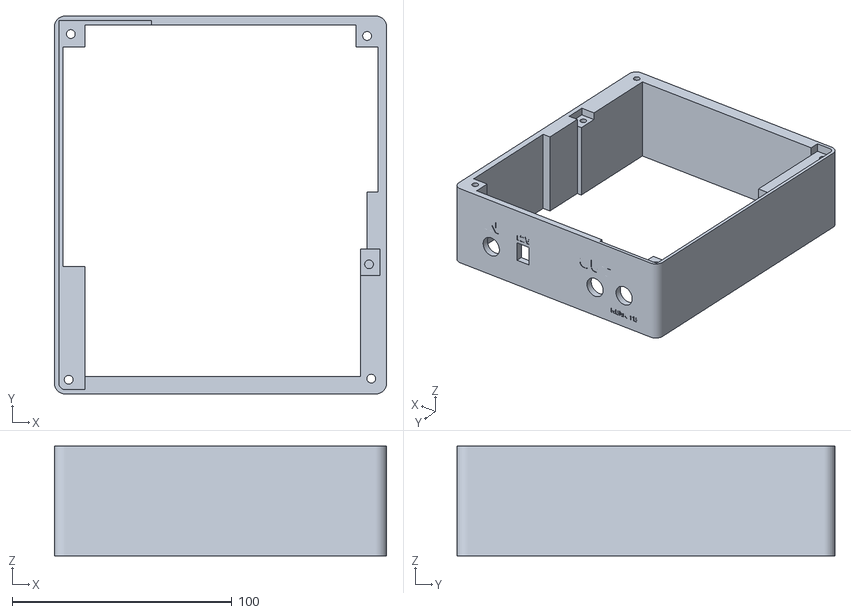
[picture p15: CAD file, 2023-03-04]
STL/Enclosure Body.stl
151.2 x 172.0 x 50.0

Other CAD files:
STL/Transport Mount.stl

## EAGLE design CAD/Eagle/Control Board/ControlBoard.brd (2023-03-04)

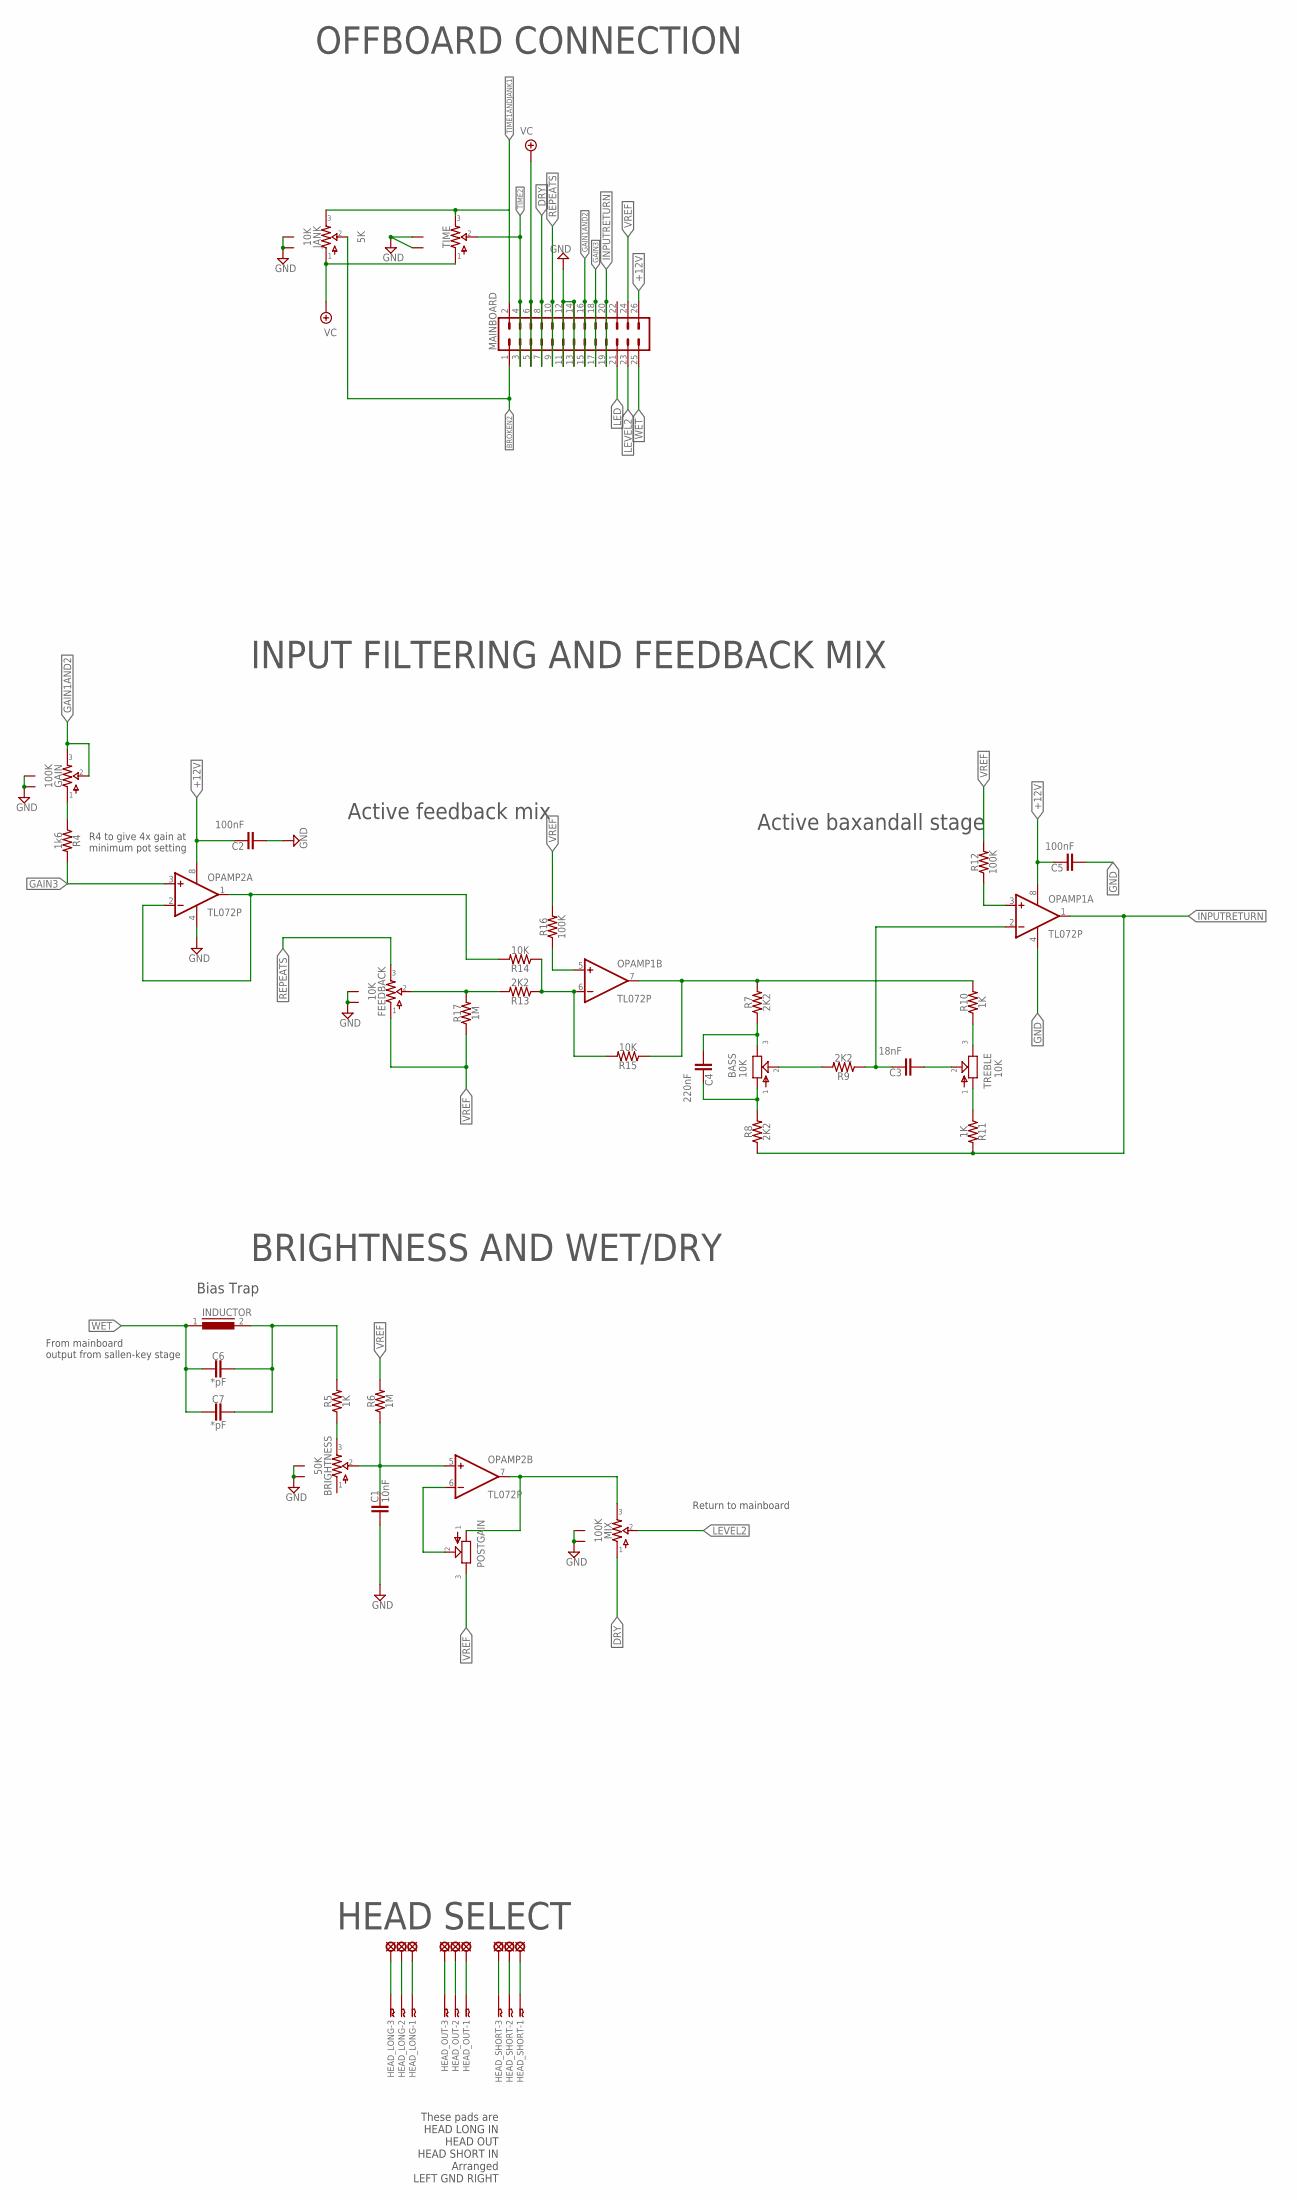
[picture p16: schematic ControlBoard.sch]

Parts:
BASS: 10K; B375P
BRIGHTNESS: 50K; 9MM_METAL_SHAFT
C1: 10nF; .33UF+
C2, C5: 100nF; 5MM
C3: 18nF; .33UF+
C4: 220nF; .33UF+
C6, C7: *pF; .33UF+
FEEDBACK: 10K; 9MM_METAL_SHAFT
GAIN: 100K; 9MM_METAL_SHAFT
HEAD_LONG: 03-JST-B3B-XH-A; B3B-XH
HEAD_OUT: 03-JST-B3B-XH-A; B3B-XH
HEAD_SHORT: 03-JST-B3B-XH-A; B3B-XH
HIN_1, HIN_2, HIN_3, HIN_4, HIN_5, HIN_6: SE14
HOUT_1, HOUT_2, HOUT_3: SE14
INDUCTOR: 82114R
JANK: 10K; 9MM_METAL_SHAFT
MAINBOARD: CONN_13X22X13; 2X13
MIX: 100K; 9MM_METAL_SHAFT
OPAMP1, OPAMP2: TL072P; DIL08
POSTGAIN: POT-EU375; B375P
R4: 1k6; 7.5MM.2
R5, R10, R11: 1K; 7.5MM.2
R6, R17: 1M; 7.5MM.2
R7, R8, R9, R13: 2K2; 7.5MM.2
R12, R16: 100K; 7.5MM.2
R14, R15: 10K; 7.5MM.2
TIME: 5K; 9MM_METAL_SHAFT
TREBLE: 10K; B375P

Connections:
+12V: C2.1, C5.1, MAINBOARD.26, OPAMP1.8 (V+), OPAMP2.8 (V+)
BIAS: C6.1, C7.1, INDUCTOR.2, R5.2
BRIGHTNESS2: OPAMP2.1 (OUT), OPAMP2.2 (-IN), R14.2
BROKEN2: JANK.P$2 (2), MAINBOARD.1
DRY: MAINBOARD.7, MAINBOARD.8, MIX.P$1 (1)
GAIN1AND2: GAIN.P$2 (2), GAIN.P$3 (3), MAINBOARD.15, MAINBOARD.16
GAIN3: MAINBOARD.17, MAINBOARD.18, OPAMP2.3 (+IN), R4.2
GND: BRIGHTNESS.P$4 (CHAS$1), BRIGHTNESS.P$5 (CHAS$2), C1.2, C2.2, C5.2, FEEDBACK.P$4 (CHAS$1), FEEDBACK.P$5 (CHAS$2), GAIN.P$4 (CHAS$1), GAIN.P$5 (CHAS$2), JANK.P$4 (CHAS$1), JANK.P$5 (CHAS$2), MAINBOARD.11, MAINBOARD.12, MAINBOARD.13, MAINBOARD.14, MIX.P$4 (CHAS$1), MIX.P$5 (CHAS$2), OPAMP1.4 (V-), OPAMP2.4 (V-), TIME.P$4 (CHAS$1), TIME.P$5 (CHAS$2)
INPUTRETURN: MAINBOARD.19, MAINBOARD.20, OPAMP1.1 (OUT), R8.1, R11.2
LED: MAINBOARD.21
LEVEL2: MAINBOARD.23, MIX.P$2 (2)
unnamed: BRIGHTNESS.P$2 (2), C1.1, OPAMP2.5 (+IN), R6.1
unnamed: HEAD_LONG.P$3, HIN_4.MP
unnamed: BASS.2, R9.2
unnamed: R10.1, TREBLE.3
unnamed: C3.2, TREBLE.2
unnamed: HEAD_LONG.P$2, HIN_5.MP
unnamed: HEAD_LONG.P$1, HIN_6.MP
unnamed: HEAD_OUT.P$3, HOUT_1.MP
unnamed: BRIGHTNESS.P$3 (3), R5.1
unnamed: HEAD_OUT.P$2, HOUT_2.MP
unnamed: HEAD_OUT.P$1, HOUT_3.MP
unnamed: OPAMP2.6 (-IN), POSTGAIN.2
unnamed: MIX.P$3 (3), OPAMP2.7 (OUT), POSTGAIN.1
unnamed: HEAD_SHORT.P$3, HIN_1.MP
unnamed: BASS.3, C4.2, R7.1
unnamed: BASS.1, C4.1, R8.2
unnamed: R11.1, TREBLE.1
unnamed: FEEDBACK.P$2 (2), R13.2, R17.2
unnamed: C3.1, OPAMP1.2 (-IN), R9.1
unnamed: OPAMP1.3 (+IN), R12.1
unnamed: OPAMP1.6 (-IN), R13.1, R14.1, R15.2
unnamed: OPAMP1.5 (+IN), R16.1
unnamed: HEAD_SHORT.P$2, HIN_2.MP
unnamed: HEAD_SHORT.P$1, HIN_3.MP
unnamed: GAIN.P$1 (1), R4.1
REPEATS: FEEDBACK.P$3 (3), MAINBOARD.9, MAINBOARD.10
TIME1ANDJANK1: JANK.P$3 (3), MAINBOARD.2, TIME.P$3 (3)
TIME2: MAINBOARD.3, MAINBOARD.4, TIME.P$2 (2)
TOBAXANDALL: OPAMP1.7 (OUT), R7.2, R10.2, R15.1
VC: JANK.P$1 (1), MAINBOARD.5, MAINBOARD.6, TIME.P$1 (1)
VREF: FEEDBACK.P$1 (1), MAINBOARD.24, POSTGAIN.3, R6.2, R12.2, R16.2, R17.1
WET: C6.2, C7.2, INDUCTOR.1, MAINBOARD.25

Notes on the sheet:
OFFBOARD CONNECTION
These pads are HEAD LONG IN HEAD OUT HEAD SHORT IN Arranged LEFT GND RIGHT
INPUT FILTERING AND FEEDBACK MIX
BRIGHTNESS AND WET/DRY
HEAD SELECT
R4 to give 4x gain at minimum pot setting
Active baxandall stage
Active feedback mix
Return to mainboard
From mainboard output from sallen-key stage
Bias Trap

Board: 2 copper layers, 46 parts (0 on the bottom side), 42 nets, no tracks yet.

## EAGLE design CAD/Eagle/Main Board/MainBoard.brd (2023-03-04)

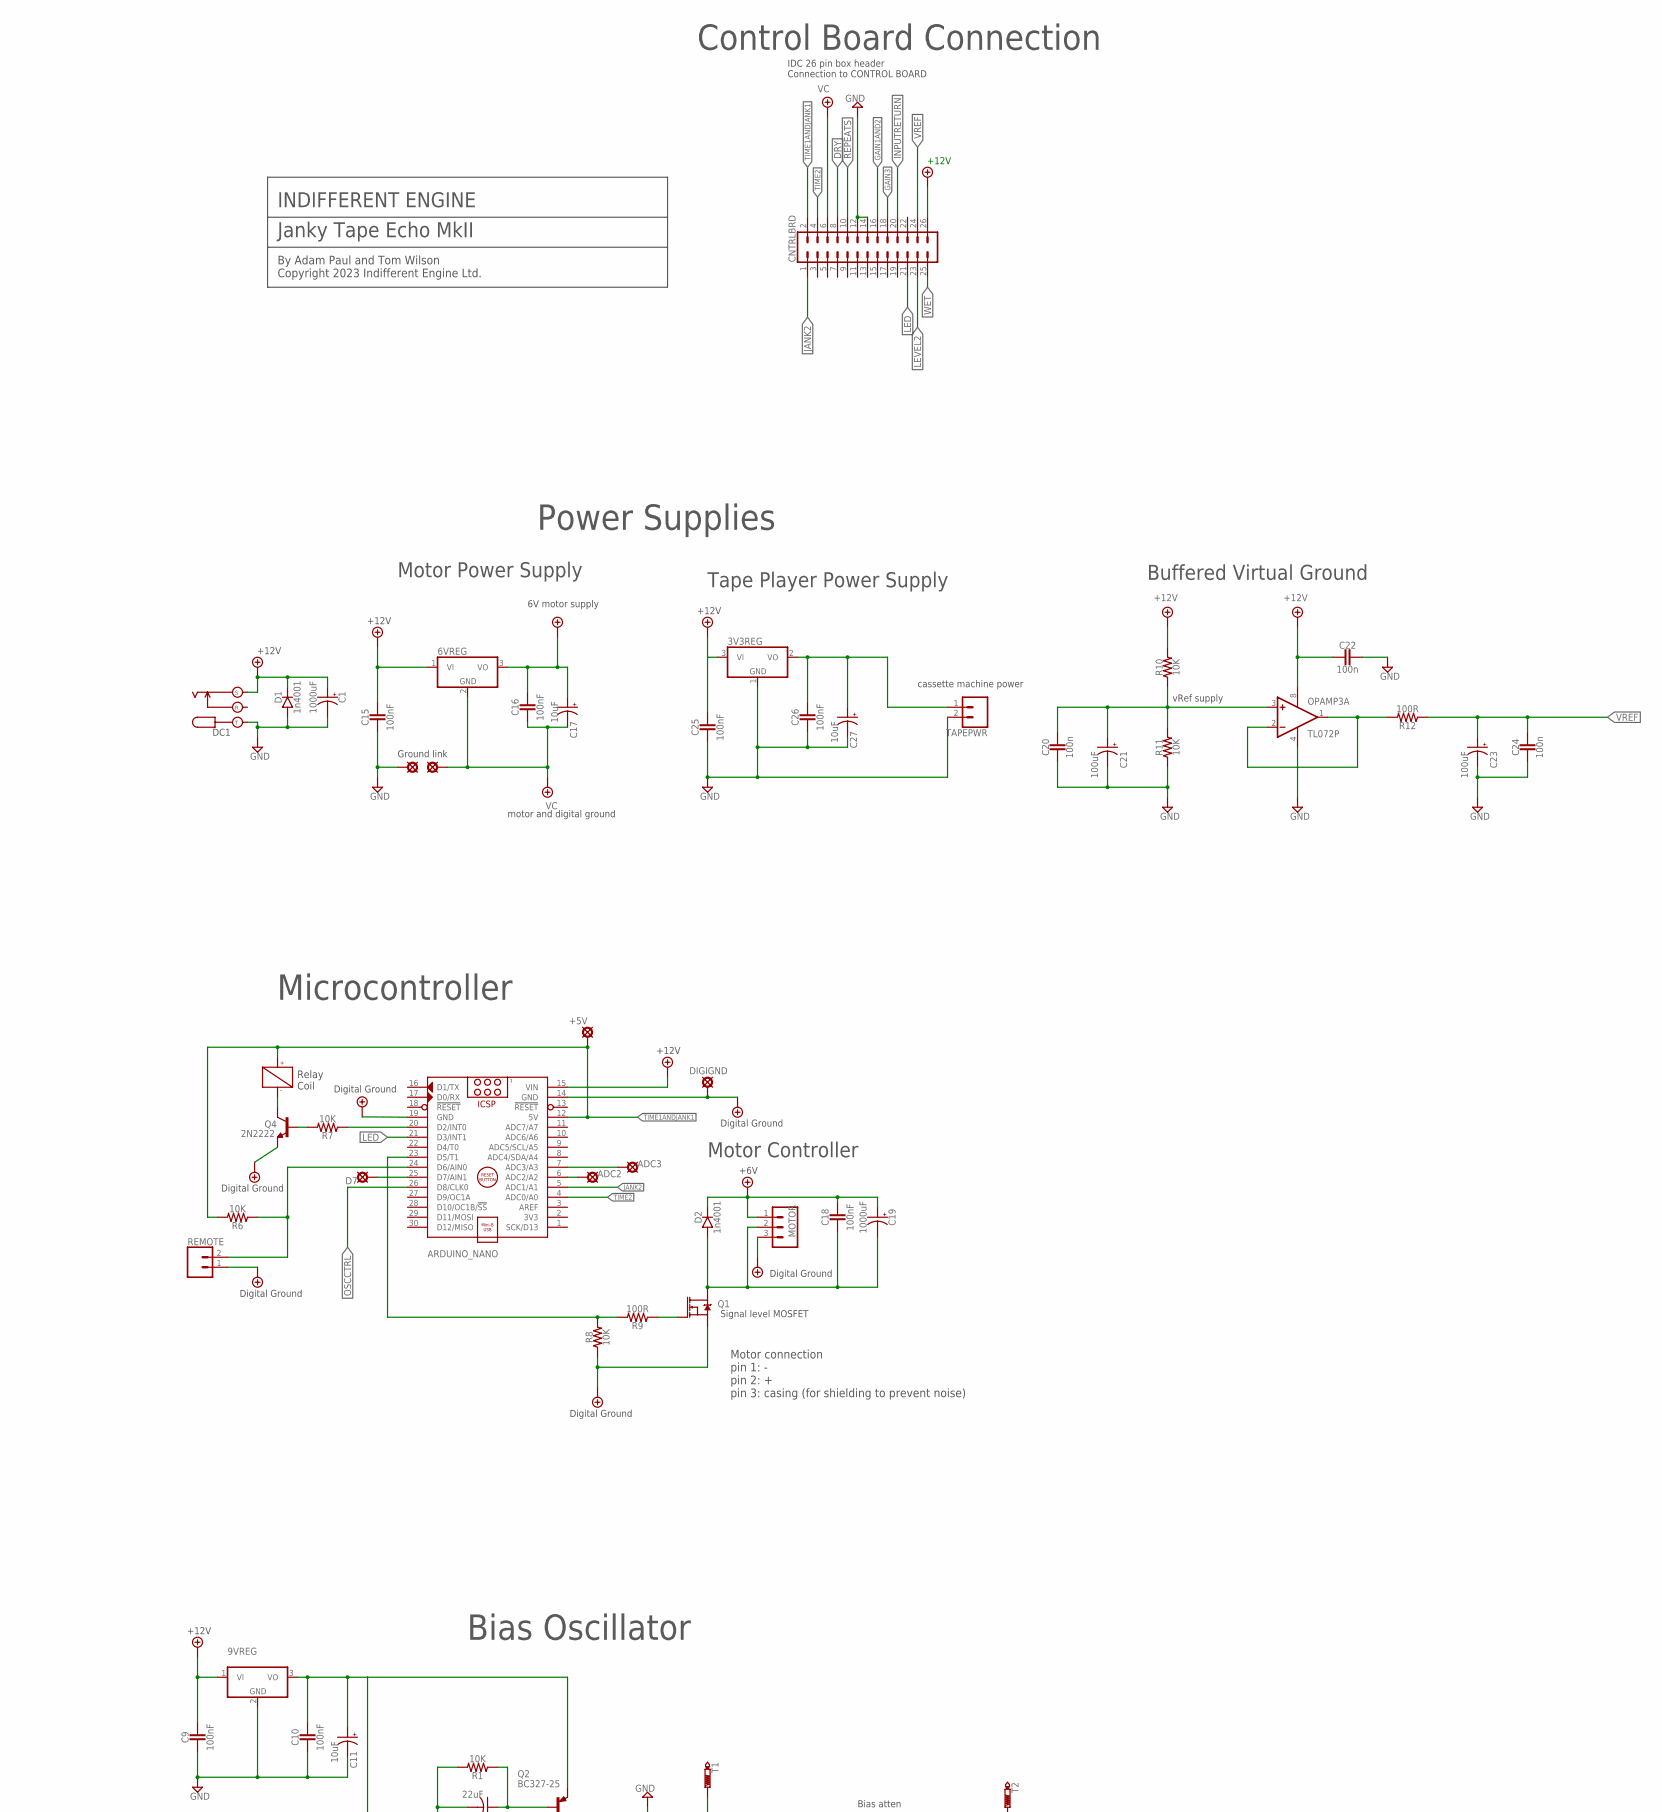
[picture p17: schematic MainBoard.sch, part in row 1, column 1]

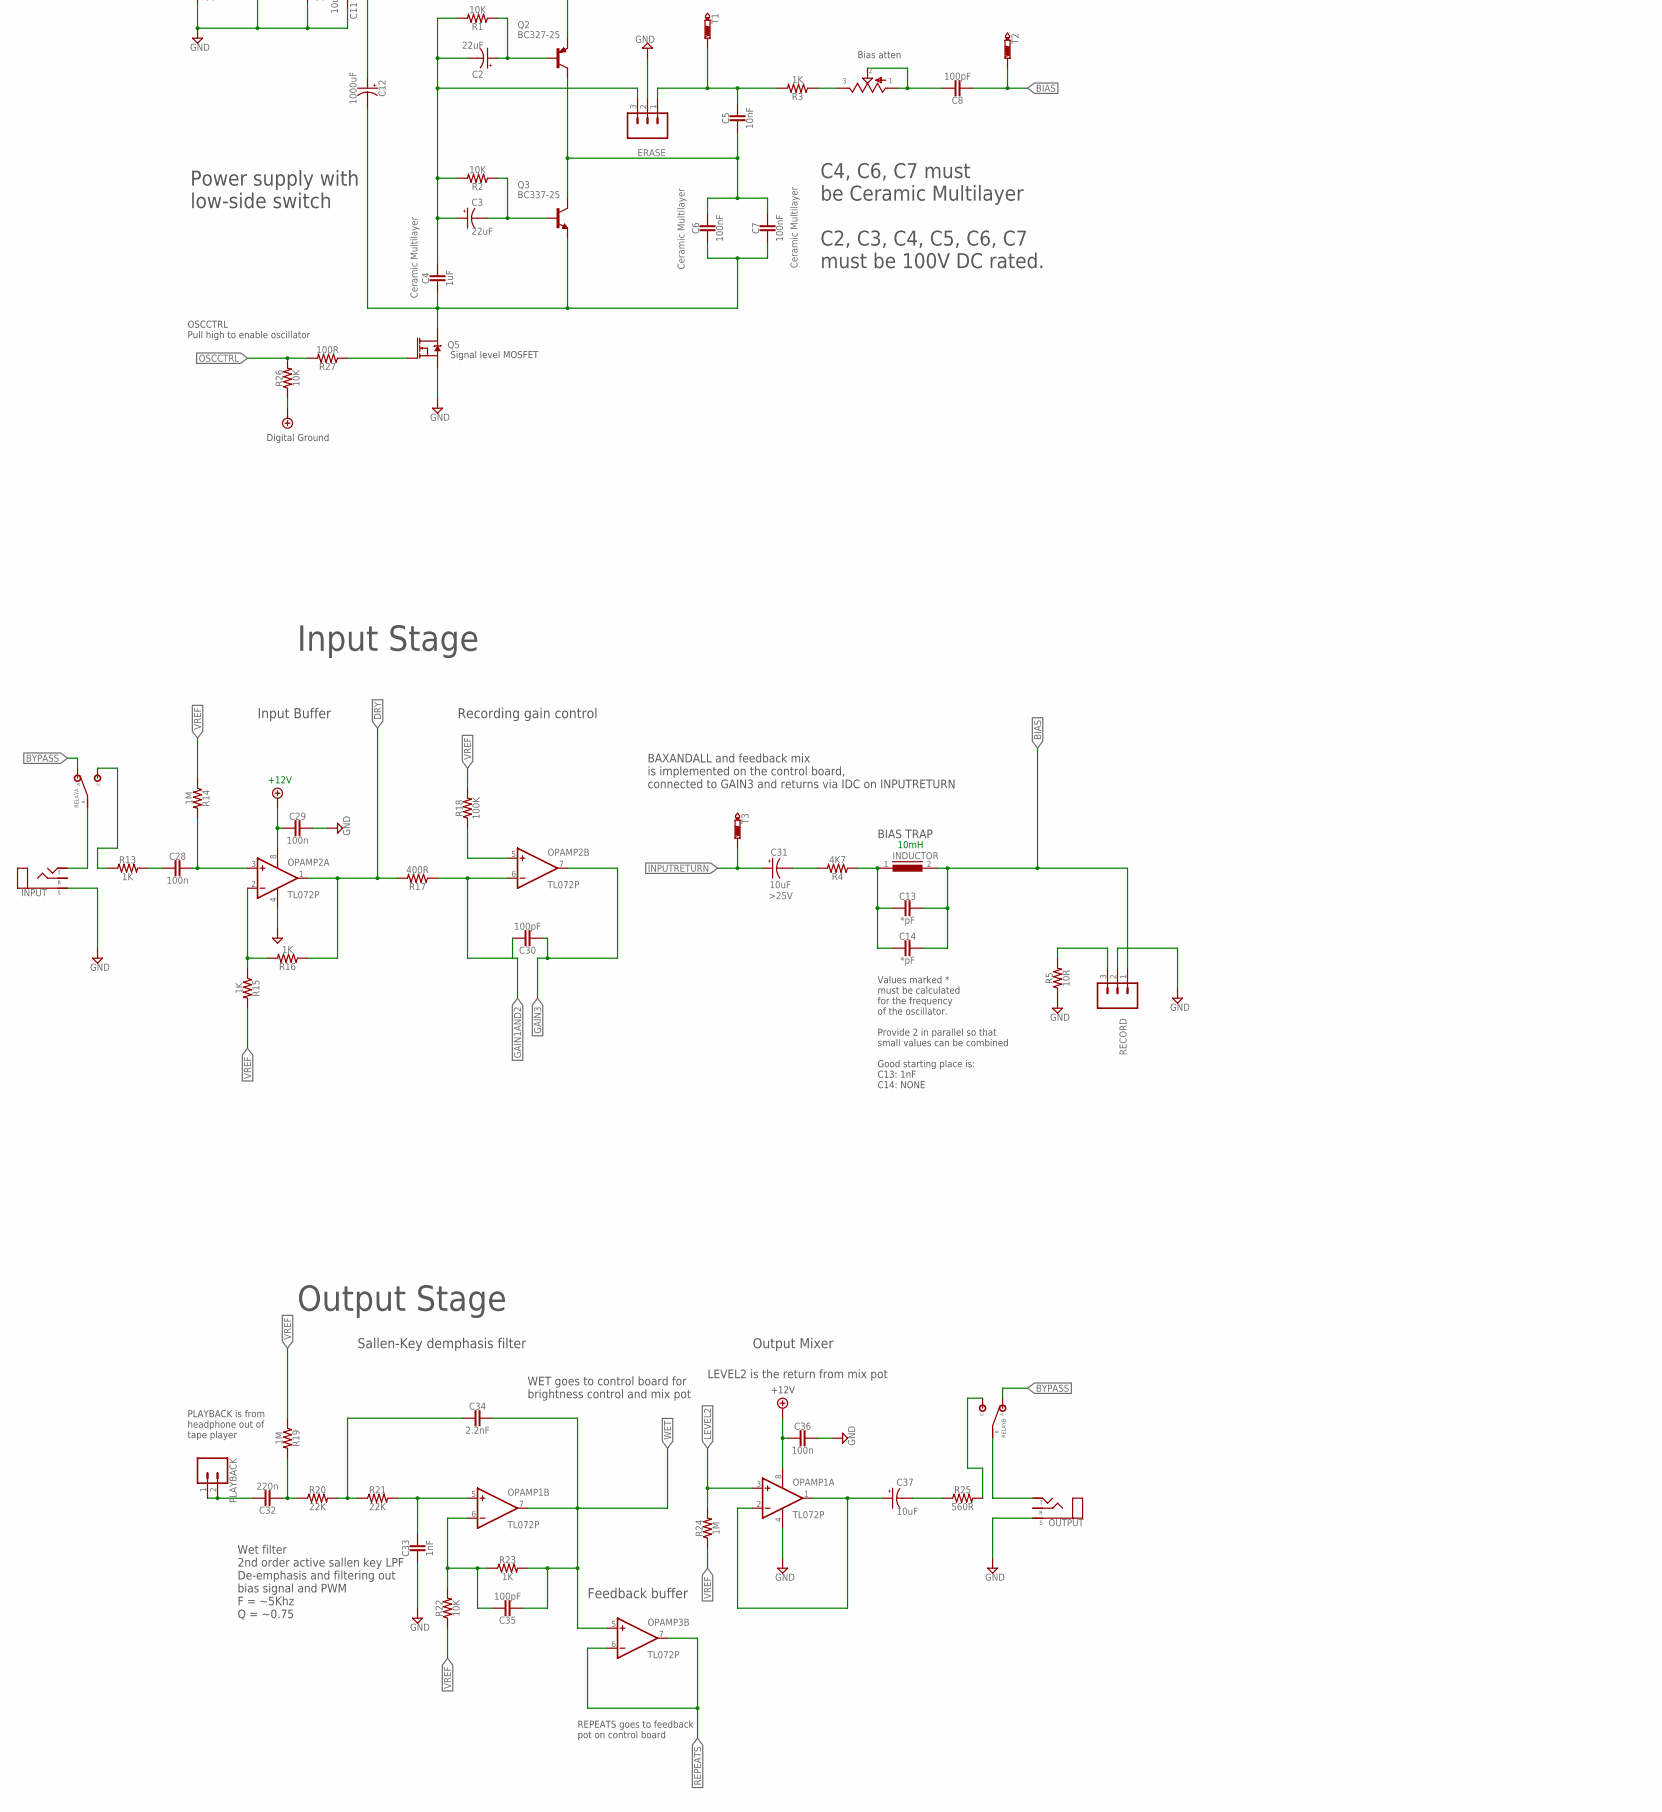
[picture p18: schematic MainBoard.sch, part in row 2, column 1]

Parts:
3V3REG: 78TO220H_2_SMALL; TO220H_SMALL
6VREG, 9VREG: 78TO220H_SMALL; TO220H_SMALL
+5V: PADL; LONG
ADC2, ADC3: PADL; LONG
ANALOG_GND: PADL; LONG
ARDUINO_NANO: ARDUINO_NANO
BIASLEVEL: POTTRIM3/8; B375P
C1, C12, C19: 1000uF; 080_5MM
C2, C3: 22uF; 050_2.5MM.1
C4: 1uF; 5MM
C5: 10nF; 5MM
C6, C7, C9, C10, C15, C16, C25, C26: 100nF; 5MM
C8, C30, C35: 100pF; .33UF+
C11, C17, C27, C37: 10uF; 050_2.5MM.1
C13, C14: *pF; .33UF+
C18: 100nF; .33UF+
C20, C22, C24, C29, C36: 100n; 5MM
C21, C23: 100uF; 050_2.5MM.1
C28: 100n; .33UF+
C31: 10uF; 050_2.5MM.1; VOLTAGE >25V
C32: 220n; .33UF+
C33: 1nF; .33UF+
C34: 2.2nF; .33UF+
CNTRLBRD: CONN_13X22X13; 2X13
D1, D2: 1n4001; DO41-3
D7: PADL; LONG
DC1: DC_KOBICONN
DIGIGND: PADL; LONG
DIGI_GROUND: PADL; LONG
ERASE: 455-1750-1-ND; 1X03
INDUCTOR: 82114R
INPUT: STEREO; STEREO_PCB
MOTOR: 455-1750-1-ND; 1X03
OPAMP1, OPAMP2, OPAMP3: TL072P; DIL08
OUTPUT: STEREO; STEREO_PCB
PLAYBACK: CONN_02; 1X02
Q1, Q5: 60V/32A/35mΩ; TO220V
Q2: BC327-25; TO92-EBC
Q3: BC337-25TO92; TO92-EBC
Q4: 2N2222; TO92-
R1, R2, R6, R7, R8, R10, R11, R22, R26: 10K; 7.5MM.2
R3, R13, R15, R16, R23: 1K; 7.5MM.2
R4: 4K7; 7.5MM.2
R5: 10R; 7.5MM.2
R9, R12, R27: 100R; 7.5MM.2
R14, R19, R24: 1M; 7.5MM.2
R17: 400R; 7.5MM.2
R18: 100K; 7.5MM.2
R20, R21: 22K; 7.5MM.2
R25: 560R; 7.5MM.2
RECORD: 455-1750-1-ND; 1X03
RELAY: IM02TSIM02TS; 8-PIN
REMOTE: CONN_02; 1X02
T1, T2, T3: PTR1B2,54; B2,54
TAPEPWR: CONN_02; 1X02

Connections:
+12V: 3V3REG.3 (VI), 6VREG.1 (VI), 9VREG.1 (VI), ARDUINO_NANO.15 (VIN), C1.+, C9.1, C15.1, C22.2, C25.1, C29.2, C36.2, CNTRLBRD.26, D1.C, DC1.S, OPAMP1.8 (V+), OPAMP2.8 (V+), OPAMP3.8 (V+), R10.2
BIAS: C8.2, C13.1, C14.1, INDUCTOR.2, RECORD.1, T2.TP
BYPASS: RELAY.3 (A), RELAY.10 (A)
DRY: CNTRLBRD.8, OPAMP2.1 (OUT), R16.1, R17.2
GAIN1AND2: C30.1, CNTRLBRD.16, OPAMP2.6 (-IN), R17.1
GAIN3: C30.2, CNTRLBRD.18, OPAMP2.7 (OUT)
GND: 3V3REG.1 (GND), 9VREG.2 (GND), ANALOG_GND.1, C1.-, C9.2, C10.2, C11.-, C15.2, C20.2, C21.-, C22.1, C23.-, C24.2, C25.2, C26.2, C27.-, C29.1, C33.2, C36.1, CNTRLBRD.12, CNTRLBRD.14, D1.A, DC1.T, ERASE.2, INPUT.P$1 (S), OPAMP1.4 (V-), OPAMP2.4 (V-), OPAMP3.4 (V-), OUTPUT.P$1 (S), Q5.3 (S), R5.1, R11.1, RECORD.2, TAPEPWR.2
INPUTRETURN: C31.+, CNTRLBRD.20, T3.TP
JANK2: ARDUINO_NANO.5 (ADC1/A1), CNTRLBRD.1
LED: ARDUINO_NANO.21 (D3/INT1), CNTRLBRD.21
LEVEL2: CNTRLBRD.23, OPAMP1.3 (+IN), R24.2
unnamed: INPUT.P$3 (T), RELAY.4 (B)
unnamed: ARDUINO_NANO.23 (D5/T1), R8.2, R9.2
unnamed: C18.2, C19.-, D2.A, MOTOR.2, Q1.2 (D)
unnamed: Q1.1 (G), R9.1
unnamed: C28.2, R13.2
unnamed: OPAMP2.5 (+IN), R18.1
unnamed: OPAMP2.2 (-IN), R15.1, R16.2
unnamed: C13.2, C14.2, INDUCTOR.1, R4.1
unnamed: Q5.1 (G), R27.1
unnamed: R5.2, RECORD.3
unnamed: R13.1, RELAY.5 (C)
unnamed: C33.1, OPAMP1.5 (+IN), R21.2
unnamed: C32.2, R19.2, R20.1
unnamed: C35.1, OPAMP1.6 (-IN), R22.2, R23.1
unnamed: C20.1, C21.+, OPAMP3.3 (+IN), R10.1, R11.2
unnamed: C34.2, R20.2, R21.1
unnamed: C28.1, OPAMP2.3 (+IN), R14.2
unnamed: C37.+, OPAMP1.1 (OUT), OPAMP1.2 (-IN)
unnamed: C37.-, R25.1
unnamed: R25.2, RELAY.8 (C)
unnamed: C2.+, Q2.B, R1.1
unnamed: C3.-, Q3.B, R2.1
unnamed: C2.-, C3.+, C4.1, ERASE.3, R1.2, R2.2
unnamed: C5.2, C6.1, C7.1, Q2.C, Q3.C
unnamed: C5.1, ERASE.1, R3.2, T1.TP
unnamed: BIASLEVEL.3, R3.1
unnamed: OUTPUT.P$3 (T), RELAY.9 (B)
unnamed: Q4.2 (B), R7.2
unnamed: BIASLEVEL.1, BIASLEVEL.2, C8.1
unnamed: C31.-, R4.2
unnamed: ARDUINO_NANO.20 (D2/INT0), R7.1
unnamed: Q4.1 (C), RELAY.1 (-)
unnamed: ARDUINO_NANO.24 (D6/AIN0), R6.1, REMOTE.2
unnamed: OPAMP3.1 (OUT), OPAMP3.2 (-IN), R12.2
unnamed: 9VREG.3 (VO), C10.1, C11.+, C12.+, Q2.E
unnamed: 3V3REG.2 (VO), C26.1, C27.+, TAPEPWR.1
unnamed: C4.2, C6.2, C7.2, C12.-, Q3.E, Q5.2 (D)
unnamed: ADC2.1, ARDUINO_NANO.6 (ADC2/A2)
unnamed: ADC3.1, ARDUINO_NANO.7 (ADC3/A3)
unnamed: ARDUINO_NANO.25 (D7/AIN1), D7.1
OSCCTRL: ARDUINO_NANO.26 (D8/CLK0), R26.2, R27.2
PLAYBACK: C32.1, PLAYBACK.1, PLAYBACK.2
REPEATS: CNTRLBRD.10, OPAMP3.6 (-IN), OPAMP3.7 (OUT)
TIME1ANDJANK1: +5V.1, ARDUINO_NANO.12 (5V), CNTRLBRD.2, R6.2, RELAY.12 (+)
TIME2: ARDUINO_NANO.4 (ADC0/A0), CNTRLBRD.4
VC: 6VREG.2 (GND), ARDUINO_NANO.14 (GND), ARDUINO_NANO.19 (GND), C16.2, C17.-, CNTRLBRD.6, DIGIGND.1, DIGI_GROUND.1, MOTOR.3, Q1.3 (S), Q4.3 (E), R8.1, R26.1, REMOTE.1
VD: 6VREG.3 (VO), C16.1, C17.+, C18.1, C19.+, D2.C, MOTOR.1
VREF: C23.+, C24.1, CNTRLBRD.24, R12.1, R14.1, R15.2, R18.2, R19.1, R22.1, R24.1
WET: C34.1, C35.2, CNTRLBRD.25, OPAMP1.7 (OUT), OPAMP3.5 (+IN), R23.2

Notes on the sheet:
6V motor supply
Motor Power Supply
Motor Controller
Input Buffer
vRef supply
BIAS TRAP
Wet filter 2nd order active sallen key LPF De-emphasis and filtering out bias signal and PWM F = ~5Khz Q = ~0.75
Output Mixer
BC337-25
Ceramic Multilayer
IDC 26 pin box header Connection to CONTROL BOARD
10mH
Bias atten
+12V
Relay Coil
Digital Ground
+6V
Signal level MOSFET
Control Board Connection
INDIFFERENT ENGINE
Janky Tape Echo MkII
By Adam Paul and Tom Wilson Copyright 2023 Indifferent Engine Ltd.
motor and digital ground
cassette machine power
Values marked * must be calculated for the frequency of the oscillator. Provide 2 in parallel so that small values can be combined Good starting place is: C13: 1nF C14: NONE
REPEATS goes to feedback pot on control board
Feedback buffer
PLAYBACK is from headphone out of tape player
Recording gain control
BAXANDALL and feedback mix is implemented on the control board, connected to GAIN3 and returns via IDC on INPUTRETURN
Power Supplies
Buffered Virtual Ground
Microcontroller
Bias Oscillator
Input Stage
Output Stage
Motor connection pin 1: - pin 2: + pin 3: casing (for shielding to prevent noise)
OSCCTRL Pull high to enable oscillator
Tape Player Power Supply
Power supply with low-side switch

Board: 2 copper layers, 101 parts (0 on the bottom side), 60 nets, no tracks yet.

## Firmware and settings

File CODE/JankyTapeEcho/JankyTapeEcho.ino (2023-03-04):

/*
 * Janky Tape Echo v2.00
 * Copyright (c) INDIFFERENT ENGINE Ltd. 2023
 * 
 * https://www.indifferentengine.com
 * 
 * Created by Adam Paul 27/12/2021
 */

//Useful for LFO
#define TWO_PI 6.283185307179586476925286766559

enum JankType {
  SINE,
  SQUARE,
  RANDOM,
  SNAG
};

enum SwitchType {
  LATCHING,
  MOMENTARY
};

/* ===================================================================================================================
 * ===================================================================================================================
 * ===================================================================================================================
 * CONFIGURE MACHINE FEATURES
 * Here you can configure the machine features.
 * 
 * CLEAN_DOWN_WHEN_DEACTIVATED 
 * Enables "auto clean-down" mode for the echo effect. When a tape echo is deactivated, the tape 
 * between the write head and read head will contain whatever audio data had already been written.
 * This means that when the effect is next engaged, that audio data will get played out. If using
 * loud, distorted high-gain sounds this can lead to a sudden loud feedback noise for a short time
 * when the effect is first engaged. All tape echos suffer from this problem. The "auto clear down" feature
 * looks to solve this issue; when enabled it will continue to run the motor for a few seconds after the effect
 * is disabled, thus passing any recorded audio past the read head and clearing it down with the erase head
 * so that you can be sure that, when the effect is next used, the tape will be blank.
 * 
 * CLEAN_DOWN_TIME_MILLISECONDS
 * How long the clean down should run for after deactivating the effect.
 * 
 * SWITCH_ON_MOTOR_KICK_TIME_MILLISECONDS
 * By running the motor at a high RPM for a few milliseconds whenever the effect is first engaged
 * it allows us to support long delay times (low RPM motor speeds) without stalling out the motor.
 * 
 * MIN_PWM_MOTOR_SPEED
 * The minimum motor speed (expressed as an 8 bit value, so a range of 0 to 255).
 * If your motor fails to spin when the TIME control is set to the longest time value
 * try increasing the the MIN_PWM_MOTOR_SPEED.
 * 
 * SWITCH_TYPE
 * What type of remote switch does this machine use? Defaults to MOMENTARY.
 * Momentary switching allows you to also use a "hold" mode :)
 */

const bool CLEAN_DOWN_WHEN_DEACTIVATED = false;
const int CLEAN_DOWN_TIME_MILLISECONDS = 1000;
const bool SWITCH_ON_MOTOR_KICK_ENABLED = true;
const int SWITCH_ON_MOTOR_KICK_TIME_MILLISECONDS = 50;
const int MIN_PWM_MOTOR_SPEED = 4;
const SwitchType SWITCH_TYPE = MOMENTARY;
/* ===================================================================================================================
 * ===================================================================================================================
 * ===================================================================================================================
 * JANKYNESS SETTINGS
 * Play with these settings to get different jankyness effects
 * 
 * SINE mode modulates the motor speed with a sine LFO.
 * SINE_JANK_MAX_HZ sets the maximum frequency of the LFO.
 * SINE_JANK_MAX_AMPLITUDE sets the LFOs max amplitude expressed as an 8-bit value.
 * The applied modulation increases both Hz and amplitude as the JANK control is turned up.
 * 
 * SQUARE mode modulates the motor speed with a square-wave LFO.
 * SQUARE_JANK_MAX_HZ sets the maximum frequency of the LFO.
 * SQUARE_JANK_MAX_AMPLITUDE sets the LFOs max amplitude expressed as 8-bit value.
 * The applied modulation increases both Hz and amplitude as the JANK control is turned up.
 * 
 * RANDOM mode modulates teh motor speed at random.
 * RANDOM_JANK_FREQUENCY sets the maximum frequency at which the speed is randomly changed.
 * RANDOM_JANK_MAX_AMPLITUDE sets the maximum speed offset from the speed determined by the TIME setting
 * The time between speed changes is random, but changes occur more frequently as the JANK control is turned up.
 * 
 * SNAG mode simulates tape snagging (those nice sudden pitch drops)
 * SNAG_MOTOR_KILL_TIME is how long to shut the motor off when a "snag" occurs (how long the tape is stuck for)
 * SNAG_JANK_MIN_DELAY is the minimum time that must elapse before another snag can occur.
 * SNAG_JANK_MAX_DELAY is the maximum time that can pass before another snag is heard.
 * The time between snags is random, but snags occur more frequently as the JANK control is turned up.
 * 
 */
//The type of jankyness we want.
const JankType jankType = RANDOM; //SINE, SQUARE, RANDOM, SNAG

//SINE mode settings
const float SINE_JANK_MAX_FREQUENCY = 10;
const float SINE_JANK_MAX_AMPLITUDE = 100;

//SQUARE mode settings
const float SQUARE_JANK_MAX_FREQUENCY = 10;
const float SQUARE_JANK_MAX_AMPLITUDE = 100;

//RANDOM mode settings
const float RANDOM_JANK_FREQUENCY = 4;
const float RANDOM_JANK_MAX_AMPLITUDE = 30;

//SNAG mode settings
const float SNAG_MOTOR_KILL_TIME = 20;
const float SNAG_JANK_MIN_DELAY = 300;
const float SNAG_JANK_MAX_DELAY = 4000;

/* ===================================================================================================================
 * ===================================================================================================================
 * ===================================================================================================================
*/

//===================================================================================================================
//These are configured against the PCB design.
//Not a good idea to change them unless you've a custom PCB
const int MOTOR_PIN = 5;
const int SWITCH_PIN = 6;
const int RELAY_PIN = 2;
//BIAS_ENABLE_PIN allows us to turn on or off the bias oscillator that drives the erase/record function of the tape machine.
//This is useful to reduce current draw, wear on the ferrous coating of the tape and noise levels whilst the pedal is bypassed.
//It also allows us to implement the "HOLD" function, where the bypass switch is held down in order to loop the contents of the tape.
const int BIAS_ENABLE_PIN = 8;

//===================================================================================================================
//Runtime switching vars
int switchOnCounter = 0;
int switchOffCounter = 0;
bool switchOn = false;
bool wasOn = false;
bool previousSwitchState = true;
unsigned long debounceTimeLast = 0;
unsigned long debounceTime = 50;
unsigned long holdTimeMin = 500;
unsigned long holdTime = 0;
bool switchHeld = false;

//===================================================================================================================
//runtime vars for jankyness
float jankValue = 0;
float pwm_Adjust = 0;
int minPwm = MIN_PWM_MOTOR_SPEED;  //this is so that we can raise the min PWM based on the jank control
int maxPwm = 30; //The motor is not linear in it's response, there's little difference in RPM between a duty cycle of 255 and 128. Therefore we use a low max value for pwm to make best use of the linear potentiometer range.
float nonLinearRange = 1000; //this is the pot value below which the motor response is considered non linear (to maximise resolution in low speed range)
float angle = 0;
int randomCount = 0;
int snagTime = 0;
bool snagged = false;
int oneSecondCount = 0;
bool builtInLEDToggle = true;

/* ===================================================================================================================
 * ===================================================================================================================
 * ===================================================================================================================
 * SETUP
 * This runs once on machine start-up, and configures the PWM frequency for the motor, the fixed 1KHz update loop (timer 2)
 * and the configures our IO pins.
*/
void setup() 
{
  
  /*
   * Set the motor PWM frequency
   * 
   * We use 62.5Khz. This is out of the audible frequency range, and above our bias frequency,
   * which makes it easy for us to use low pass filters to target both bias and PWM noise.
   */
  TCCR0B = TCCR0B & B11111000 | B00000001; //62500 Hz
  
  // Setup Timer 2 for interrupt frequency 1Khz
  // Timer 2 forms our fixed-rate update function
  cli(); // stop interrupts
  TCCR2A = 0; // set entire TCCR2A register to 0
  TCCR2B = 0; // same for TCCR2B
  TCNT2  = 0; // initialize counter value to 0
  // set compare match register for 1Khz increments
  OCR2A = 249; // = 16000000 / (64 * 1000) - 1 (must be <256)
  // turn on CTC mode
  TCCR2B |= (1 << WGM21);
  // Set CS22, CS21 and CS20 bits for 64 prescaler
  TCCR2B |= (1 << CS22) | (0 << CS21) | (0 << CS20);
  // enable timer compare interrupt
  TIMSK2 |= (1 << OCIE2A);
  sei(); // allow interrupts

  //Configure the various input and output pins we need 
  pinMode(SWITCH_PIN, INPUT_PULLUP);
  pinMode(RELAY_PIN, OUTPUT);       
  pinMode(BIAS_ENABLE_PIN, OUTPUT); 
  pinMode(LED_BUILTIN, OUTPUT);
  pinMode(MOTOR_PIN, OUTPUT);
  
 
  //Start up the serial port. This is useful for debugging.
  Serial.begin(115200);
  Serial.println("JANKY TAPE ECHO");
  Serial.println("Firmware version 2.00");
  Serial.println("(C) Indifferent Engine Ltd 2023");
  Serial.println("[the::compartment::is::flooded::with::radiation]");
}


/* ===================================================================================================================
 * ===================================================================================================================
 * ===================================================================================================================
 * LOOP
 * This runs every frame. In here we process IO and any non-time-dependent logic.
*/
void loop() {
  
  //read switch state, we use this to turn the effect on/off.
  bool switchState = digitalRead(SWITCH_PIN) == HIGH ? true : false;

  //Switching logic, with debounce
  if ((jankyMillis() - debounceTimeLast) > debounceTime) 
  {
     if (switchState != previousSwitchState) 
     {
        if (SWITCH_TYPE == LATCHING) 
        {
          switchOn = switchState;
        }
        else 
        {
          if (!switchState && 
                previousSwitchState) {
            //switch was just depressed, so set the hold time
            //so that we can calculate how long the switch has been held down for
            holdTime = jankyMillis();
          }
          if (switchState 
                && !previousSwitchState)
          {
            //switch was just released,
            //so perform the effect on/off toggle
            //Unless the switch was in the "held" mode, then we ignore the switch release
            if (!switchOn || !switchHeld) {
              switchOn = !switchOn;
            }
          }  
        }
        previousSwitchState = switchState;
        debounceTimeLast = jankyMillis();
     }
  }

  //When using momentary switching, we can set a hold mode to do something interesting when the switch is held down.
  if (SWITCH_TYPE == MOMENTARY
      && switchOn 
      && !switchState) 
  {
    if (jankyMillis() - holdTime > holdTimeMin) 
    {
      //Switch is being held, set the flag
      switchHeld = true;
    }
  }
  else {
    //Switch is not being held, clear the flag
    switchHeld = false;
  }

  //Some more switch logic
  if (wasOn && !switchOn) 
  {
    //switch was just deactivated this frame
    switchOffCounter = 0;
  }
  else if (!wasOn && switchOn) {
    //switch was just activated this frame
     switchOnCounter = 0;
  }

  //read the digital rotary controls for TIME and JANK
  //ADC on the nano is 10bit, meaning a range of 0 to 1024
  int timePotValue = analogRead(A0); //0->1024
  int jankPotValue = analogRead(A1); //0->1024
 
 
  //Get a normalised jank value (meaning between 0 and 1)
  jankValue = (1.0f / 1024) * jankPotValue;
  int pwmValue = 0;
  /*
   * The TIME value is used to work out what pwm value to send to the motor
   * In the v2, the motor controller is very non-linear, so we hack in a 
   * little non-linear response here to allow us to get more resolution 
   * out of the potentiometer. It levels back out to linear at the top
   * of the range.
   * 
   * [todo] make this not so... horrible. Maybe a function look up table?
  */
  if ((1024-timePotValue) < nonLinearRange) {

    //Map potentiometer ADC reading to PWM output value
    //we do this via an inverse parabola (x = y * y), resulting in y = sqrt(x)
    float minRad = TWO_PI/4.0f;
    float maxRad = TWO_PI/2.0f;
    float val = (((maxRad-minRad)/nonLinearRange) * (1024-timePotValue)) + minRad;
    
    float y = (sqrt((1024-timePotValue)/nonLinearRange));
    pwmValue = (int) (((maxPwm - minPwm) * y) + minPwm);
  }
  else {
    //A little bit of linear response at the top of the pot range
    pwmValue = ((255.0f - maxPwm) / (1024.0f - nonLinearRange)) * ((1024.0f-nonLinearRange)-timePotValue);
    pwmValue += maxPwm;
  } 

  //Apply the pwm_Adjust calculated from the Jank settings
  pwmValue += pwm_Adjust;
  pwmValue = switchOn ? constrain(pwmValue, minPwm, 255) : 0;  
  
  //if we're currently simulating a tape "snag", then turn off the motor
  pwmValue = snagged ? 0 : pwmValue;

  bool cleaningDown = false;
  //If tape auto-clean-down is activated, we handle that here.
  //If the effect is off but we're still cleaning down the tape then keep running the motor
  if (CLEAN_DOWN_WHEN_DEACTIVATED
      && !switchOn) 
  {
    pwmValue = switchOffCounter < CLEAN_DOWN_TIME_MILLISECONDS ? 255 : 0;
    cleaningDown = switchOffCounter < CLEAN_DOWN_TIME_MILLISECONDS ? true : false;   
  }

  //This kicks the motor at full power for the first few millis after the effect is switched on.
  //That way, if the TIME value is set long (i.e. low motor speed), the motor can get enough current
  //to actually start. This allows us to support much lower minimum PWM values than would otherwise
  //be possible
  if (switchOn 
      && SWITCH_ON_MOTOR_KICK_ENABLED
      && switchOnCounter < SWITCH_ON_MOTOR_KICK_TIME_MILLISECONDS) 
  {
    pwmValue = 255;
  }

  //write out pwm value to motor control pin
  analogWrite(MOTOR_PIN,pwmValue);
  
  //set pin values for switching relay, LEDs and what not.
  digitalWrite(LED_BUILTIN, builtInLEDToggle ? HIGH : LOW);
  //Set the true bypass switching to the correct position by controlling the relay
  digitalWrite(RELAY_PIN, switchOn ? HIGH : LOW);
  //Enable or disable the bias oscillator
  digitalWrite(BIAS_ENABLE_PIN, (switchOn && !switchHeld) || cleaningDown ? HIGH : LOW);
  
  //remember the previous state of the switch for comparison next frame
  wasOn = switchOn;
}

//Millis function that compensates for oscillator change
unsigned long jankyMillis() {
  return millis()/64;
}

/* ===================================================================================================================
 * ===================================================================================================================
 * ===================================================================================================================
 * ISR TIMER2
 * This runs every 1 millisecond. We do time-dependent work in here, like processing LFOs and what not.
 * Essentially, any logic that benefits from being run at a fixed rate.
*/
ISR(TIMER2_COMPA_vect){

  //
  //Handle our Jankyness calculations for various jankyness types.
  //
  if (jankType == SINE 
      || jankType == SQUARE)
  {
    float hZ = jankValue * (jankType == SINE ? SINE_JANK_MAX_FREQUENCY : SQUARE_JANK_MAX_FREQUENCY);
    float amplitude = jankValue * (jankType == SINE ? SINE_JANK_MAX_AMPLITUDE : SQUARE_JANK_MAX_AMPLITUDE);

    //We have to lower the maximum speed of the motor
    //Otherwise if the TIME control is set to minimum (motor at it's fastest)
    //then the jank control won't function correctly, as it will be trying to set the
    //pwm to 255 + the jank value. So we reduce the pwm by the amplitude of the jank LFO
    maxPwm = (int)(255.0f - amplitude);
    minPwm = (int)(MIN_PWM_MOTOR_SPEED + amplitude);
    
    //A simple LFO that can easily be converted into a sine wave.
    if (hZ != 0) {
      angle += (TWO_PI * hZ ) / 1000.0f; // interrupt happens at 1Khz, so /1000
      if (angle >=TWO_PI) 
      {
        angle -= TWO_PI;
      }
    }
    else 
    {
      angle = 0;
    }

    if (jankType == SINE) 
    {
      pwm_Adjust = sin(angle) * amplitude;
    }
    else 
    {
      pwm_Adjust = amplitude * (angle < PI ? -1.0f : 1.0f);
    }                       
    
  }
  else if (jankType == RANDOM) 
  {
    if (randomCount <= 0) 
    {
      float amplitude = jankValue * RANDOM_JANK_MAX_AMPLITUDE;
      pwm_Adjust = random(-amplitude*0.5f, amplitude*0.5f);
      randomCount = random((1.0f - jankValue) * (1000.0f/ RANDOM_JANK_FREQUENCY));
    }
    else 
    {
      randomCount -= 1;
    }   
  }
  else if (jankType == SNAG) 
  {
    if (snagTime > 0) {
      snagged = true;
      --snagTime;
    }
    else {    
      snagged = false;
      if (randomCount <= 0) 
      {
        float amplitude = jankValue * RANDOM_JANK_MAX_AMPLITUDE;
        pwm_Adjust = 0;
        randomCount = SNAG_JANK_MIN_DELAY + random((1.0f - jankValue) * SNAG_JANK_MAX_DELAY);
        snagTime = SNAG_MOTOR_KILL_TIME;
      }
      else 
      {
        randomCount -= 1;
      } 
    }
  }
  //incremement the time since switch was pressed
  if (switchOnCounter < SWITCH_ON_MOTOR_KICK_TIME_MILLISECONDS)
  { 
    ++switchOnCounter;
  }
  if (switchOffCounter < CLEAN_DOWN_TIME_MILLISECONDS)
  { 
    ++switchOffCounter;
  }

  //toggle the built in LED so we can see at a glance if our program is executing
  if (oneSecondCount >= 250) {
    builtInLEDToggle = !builtInLEDToggle;
    oneSecondCount = 0;
  }
  ++oneSecondCount;
}



//===================================================================================================================
//===================================================================================================================
//===================================================================================================================
//And that's it. Go buy a T-Shirt or something, alright?
//https://www.indifferentengine.com

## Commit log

2023-03-04 Janky Tape Echo v2.00 release
    [15RAA2.stl, Belt.stl, Bill Of Materials.xlsx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]
2023-06-20 -Increased thickness of lid front slightly to improve print reliability. -Added TC62 and 25PBK8 head adapters
    [25PBK8.stl, Enclosure Lid.stl, EnclosureLid.stl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]

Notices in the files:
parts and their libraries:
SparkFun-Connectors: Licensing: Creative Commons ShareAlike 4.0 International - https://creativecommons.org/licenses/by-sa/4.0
